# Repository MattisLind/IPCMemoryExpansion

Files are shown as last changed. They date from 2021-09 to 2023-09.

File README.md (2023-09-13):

# HP Integral PC Memory Expansion board

HP Integral PC

The HP Integral PC was a portable 68000 UNIX based computer introduced in 1984. The computer included a floppy drive as mass storage and a printer was built in. The screen was a electroluminicent screen. The computer has a HPIB connector to attach to external devices. External disks can be attached through HPIB.

The computer has a two expansion slot where various peripherals can be installed. For example serial boards or memory expansion boards. It was also possible to install ROM boards. The software engineering ROM has 2Mbyte of ROM expansion and when installed appear as 8 disk devices in the Unix system.

The project aims at creating a 7M RAM and 8M ROM memory expansion to the HP Integral computer. RAM is implemented using a single SRAM chip and ROM is implemented using a single NOR FLASH ROM chip. DIP-switches are used to map the ROM into the various ROM areas of the Integral.

## Levelshifting

All signals are level shifted from 5V TTL to 3.3V LVTTL using six 74LVC245 which has 5V tolerant inputs. The two open-collector signals, NBDTACK and NBIMA is handled by 1 74LS38 chip.

## Address decoding

A Xilinx XC2C32A CPLD is used for all address decoding and ROM remapping. The VHDL is provided [here](https://raw.githubusercontent.com/MattisLind/IPCMemoryExpansion/main/XILINX/IntegralMemExp/main.vhd).

## DIPSWITCH

The board is using a piano-type dipswitch for easy access from the side. When the switch is in the up position in corresponds to the off condition or digital 1 signal. When the switch is in the down position this corresponds to a on condition or 0 signal. X means that the position of the switch is irrelevant.

DIPSW0 to DIPSW5 is used for controlling the ROM mapping in the address space.

DIPSW7 is used for enabling and disabling the busdrivers and DIPSW6 is connected to RESET of the processor. Thus the processor portion can be completely disabled when both these switches are pushed down (on). They should be in the UP (off) position so that the processor runs and can access the memory when trying to upload to the flash memory onboard. When used in the Integral PC they should be in the DOWN (on) position to stop the processor and disable processor access to the memory.

## ROM
The mapping of the FLASH ROM memory is controlled by six dipswitches as follows:

| Integral address range | DIPSW0 | DIPSW1 | DIPSW2 | DIPSW3 | DIPSW4 | DIPSW5 | Flash memory range | Used for |
|---|---|---|---|---|---|---|---|---|
| 000000 - 07FFFF | Down(0) | Down(0) | X | X | X | X |  000000-07FFFF | SYS V ROM|
| 000000 - 07FFFF | Down(0) | Up(1) | X | X | X | X |  080000-0FFFFF | DiagA ROM|
| 000000 - 07FFFF | Up(1) | Down(0) | X | X | X | X |  100000-17FFFF | DiagB ROM|
| 000000 - 07FFFF | Up(1) | Up(1) | X | X | X | X |  NONE | Internal ROM used |
| 080000 - 0FFFFF | X | X | Down(0) | X | X | X |  NONE | NONE |
| 080000 - 0FFFFF | X | X | Up(1) | X | X | X |  180000-1FFFFF | BASIC ROM |
| 100000 - 1FFFFF | X | X | X | X | X | Down(0) |  NONE | |
| 100000 - 1FFFFF | X | X | X | X | X | Up(1) |  600000-6FFFFF | AUX ROM 3|
| 200000 - 3FFFFF | X | X | X | Down(0) | Down(0) | X |  200000-3FFFFF | SE ROM |
| 200000 - 3FFFFF | X | X | X | Down(0) | Up(1) | X |  400000-5FFFFF | AUX ROM 1|
| 200000 - 3FFFFF | X | X | X | Up(1) | X | X |  NONE | NONE |
| 300000 - 4FFFFF | X | X | X | X | X | Down(0) |  NONE | NONE |
| 300000 - 4FFFFF | X | X | X | X | X | Up(1) |  700000-7FFFFF | AUX ROM 2 |

There is a STM32F407ZET SoC makes the board look like a USB stick when the USB port is connected to a host computer. 

The ROM is implemented in one single 8 Mbyte SST38VF6401 chip.

## RAM

Normally Integral memory is implemented using memory board sized up to 1 MByte. Each memory board responds to a read port which provide an ID for the board and a writable base address register. The Integral will use these to identfiy each memory board and configure its starting address. However the memory sizing of HP-UX system is completely independent of the memory configuration descibed preiously meaning that these configuaration is not necessary to get the Integral to detect the full memory. This has been verified using the MAME emulation of the Integral.

All this obviously that it would be very much easier to implement a RAM expansion board since it only requires that it would match the RAM address range 800000-EFFFFF.

The RAM is implemented in one single AS6C6416 4M x 16 SRAM memory chip. 

## Testing and design fault finding.

Obviously when testing the board for the first time it didn't work at all. Of course I tested many different ways to get it working. But in the end I think that one main problem was the use of UDS/LDS instead of AS strobe. On the standard 68000 that would probably have worked just fine. But on the HP Integral he AS strobe is not at all the AS strobe from the processor. It has gone through plenty of logic until the AS signal found in the expasion connector is generated. Thus the use of the AS signal is a must. Gating with that signal made the RAM expansio work fine.

Since the 74LVC245 inputs are CMOS there wil be no current flowing towards the expansion board. When I attached a bus extender board to be able to measure on the board the added buslength seemed to cause trouble. Adding bus terminating resistors at the 74LVC245 inputs seemed to fix the issue. To better adapt the 74LVC245 driver to the bus impedance a low ohm resistor was inserted in the bus line path for the data bus.

All these changes resulted in a second spin of the board.

## Spin 2

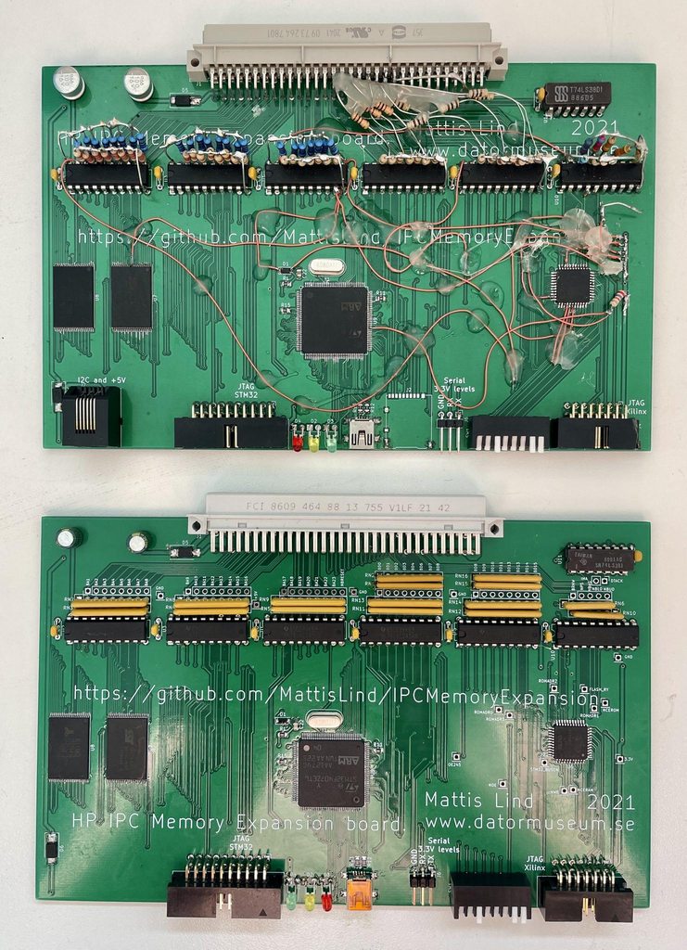
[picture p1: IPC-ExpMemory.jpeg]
Boards


Spin 1 became quite messy when trying to fix all small problems so I decided on a spin 2. I also added test points to make it easier to measure on the board, a major issue on the first spin was that it was so hard to take measurements. After spin 2 came back from the JLCPCB I found that it was virtually impossible to get hold of the STM32 chip and the CPLD, so the project got dormant until sping 2023 when I eventually was able to order chips.

There were some small changes made to the CPLD VHDL code for spin 2 ~~which to this date has not yet been tested (2023-07-24). I hope to be able to test the board soon.~~
Spin 2 has now been tested and appears to work correctly. Follow instructions further down to install the board.

## Firmware

There are two firmwares. One Arduino style .ino-sketch which I used for testing and the a STM32Cube applicaton that is the production code. I used STM32 because it was so simple to wrap up the USB mass storage stuff. The code essentially enables the FSMC controller of the chip and enables the USB mass storage code, then it responds to read and writes to the memory. While the USB-cable is connected the green LED will blink. The yellow LED will blink when a read is performed and the red will blink when a write is performed.

## Installation

There are three steps that need to be taken to install the all needed software/firmware to get the board running.
1. Program the CPLD
2. Install the STM32 firmware
3. Upload integral software to the board

For all these steps the USB connector of the board need to be connected to a USB outlet to the computer. This will thus supply the board with power and in the third step also make the board able to communicate with the host.

### Program the CPLD

The CPLD code is written in VHDL and I have used the Xilinx ISE version 14.7. In order to just install the existing JEDEC file provided in the repo it is only necessary to use the Impact tool in the Xilinx ISE suite. Download, start Impact, attach the Xilinx download cable and make sure that the device is detected. Then select the main.jed file and program the device.

### Install the STM32 firmware

You need both the STM32CubeIDE and STM32CubeProgrammer which has to be downloaded from the ST webpage. Use defaults when installing the software.

When installation is ready start STM32CubeIDE and select the "Open Projects from file System" option in the menu. Select the folder " Software/STM32CubeIDE/workspace_1.7.0 /HP IPC Memory Expansion/" in this repo. In the project menu, select the Build Configurations. This will open a submenu which where you can do "Set Active" Select "Release"

Now do "Build All" from the project menu and the full software will be built.

Now start the STM32CubeProgrammer software nd make sure the STM32 download canle is attached to the board and that power is supplied to the board using the USB cable. In this step DIPSW 6 and DIPSW 7 has to be in the up posistion.

Select the "HP IPC Memory Expansion.elf" binary in the Release folder and do a "Erase and program" operation.

### Uploading Integral software to the board

The idea is to use the Linux dd command to transfer the image-file generated by the build.sh shellscript in ROMS folder. When doing so the red and green LEDs should blink. It should also be possible to read back the content stored using dd and compare with the actual file. It is important to write the image to the topmost 8M of the USB device created when the board is connected over USB. The top 8M is mapped to the flash memory while the lower 8M is mapped to the SRAM.

Thus this command is needed to write the flash:

```
sudo dd if=flash_image.bin of=/dev/sd<x> bs=1k seek=8192
```
where ```/dev/sd<x>``` is the device that is allocated for the mass storage device that the board is acting as. Check using ```dmesg``` what device is created when it is plugged into the USB-port.

## Schematic 

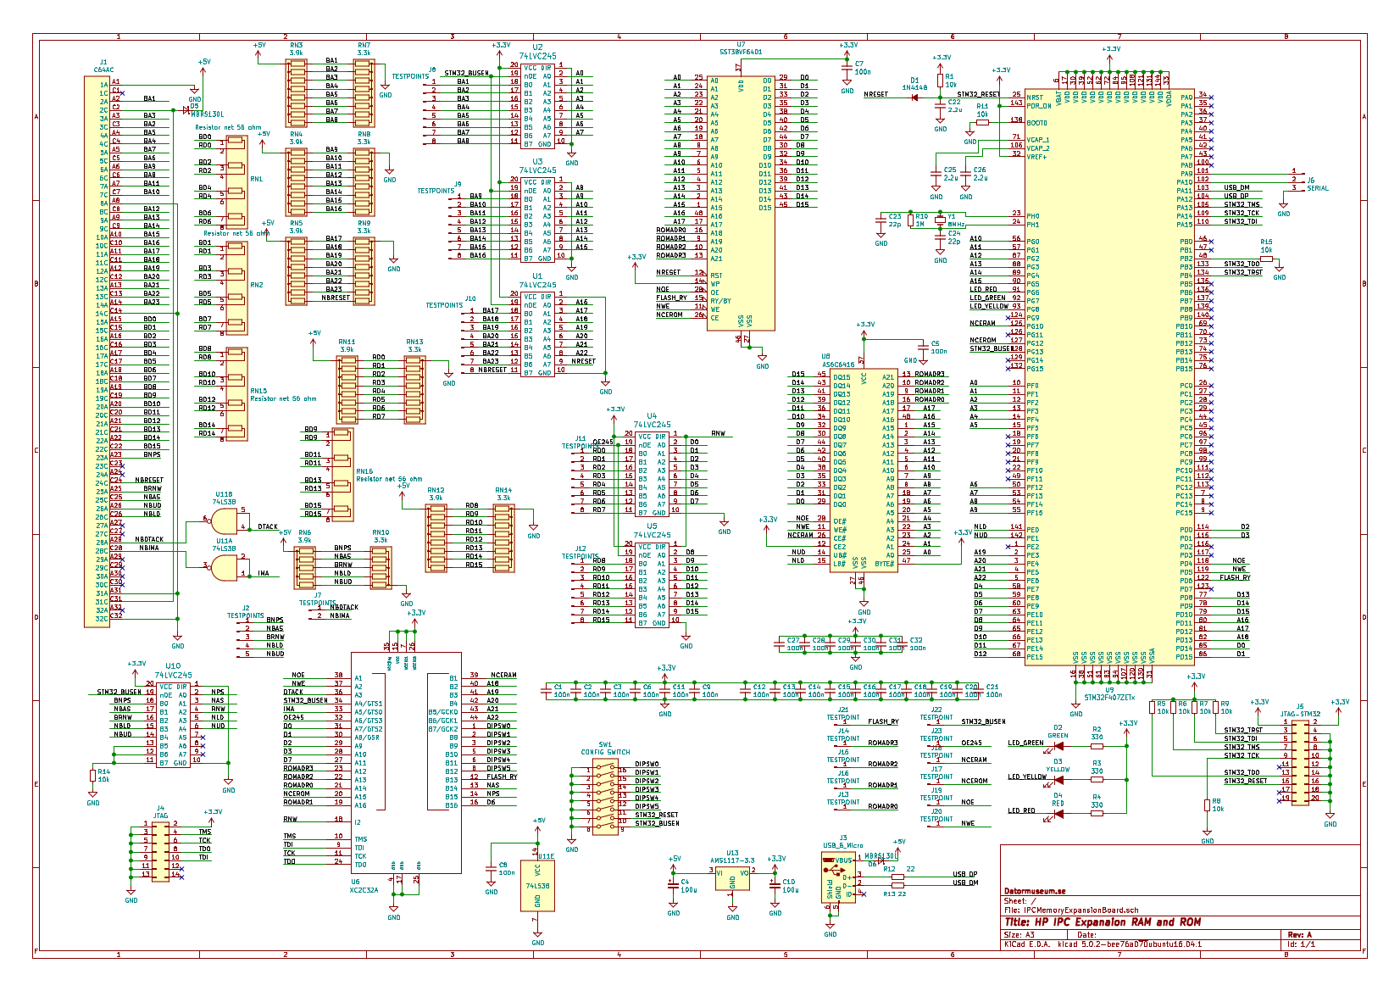
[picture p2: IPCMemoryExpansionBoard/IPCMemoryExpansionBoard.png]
Schematic


## Install instructions by Carl Claunch

After spin 1 was completed I was not able to get components for spin 2 although the board had been fabricated. All this due to the post-covid semiconductor crunch. In July 2023 I got contacted by Carl who had been asked to help out to do the installation of the firmware. As we sorted out how topoerform the steps (which I had more or less forgotten since I initially designed it) he created a nice document which describes the steps do be done. I link it below:

[Install instructions by Carl Claunch](https://github.com/MattisLind/IPCMemoryExpansion/blob/main/HP%20Integral%20board%20instructions.pdf)

## BOM
This is a BOM for the spin 2 board:

| Component designator | Description | Mouser order number | Misc. |
|---|---|---|---|
| R1,R5,R6,R7,R8,R9,R11,R14,R15| 10kOhm SMD 0805 |  -  | |
| R2,R3,R4 | 330 Ohm SMD 0805 | - | |
| R10 | 1MOhm SMD 0805 | - | |
| R12,R13 | 22 Ohm SMD 0805 | - | |
| RN1,RN2,RN15,RN16 |  network 4 x bussed 56 Ohm THT | 652-4608X-2LF-56 | |
| RN3,RN4,RN5,RN6,RN11,RN12 | network 8 x star 3.9 KOhm  THT | 652-4609X-1LF-3.9K | |
| RN10 | network 5 x star 3.3 KOhm THT | 652-4606X-1LF-3.3K | |
| RN7,RN8,RN9,RN10,RN13,RN14 | network 8 x star 3.3 KOhm THT | 652-4609X-1LF-3.3K | |
| RN6 |  network 5 x star 3.9 KOhm | 652-4606X-1LF-3.9K | |
| C1,C2,C3,C5,C6,C7,C8 | 100 nF Ceramic THT, RM5 | - | |
| C4,C10 | 100 uF Electrolytic THT, RM 2.5 | - ||
| C9,C11,C12,C13,C14,C15,C16,C17,C18,<BR>C19,C20,C21,C27,C28,C29,C30,C31,C32 | 100 nF SMD 0805 | - ||
| C22,C25,C26| 2.2 uF SMD, 0805 | - | C25 is on the underside just <BR>below the processor chip,<BR>close to C29. The silkscreen is a bit bad |
| C23,C24 | 22 pF SMD, 0805 | - | |
| D1 | IN4148 SMD | 750-1N4148W-HF | Located on the top side <BR>close to the processor |
| D2 | LED green 3mm THT | 859-LTL-4231N | |
| D3 | LED yellow 3mm THT | 859-LTL-4251N | |
| D4 | LED red 3mm THT | 859-LTL-4221N | |
| D5,D6 | MBRS130L SMD, 2010 | 78-VS-MBRS130L-M35BT | |
| SW1 |  8 DIP switch - piano style THT | 774-1958MS | |
| U1,U2,U3,U4,U5,U10 | 74LVC245 THT | 595-SN74LVC245ANE4 | |
| U6 | XC2C32A SMD | 217-XC2C32A-6VQG44I | |
| U7 | SST38VF6401 SMD | 804-38VF64019CEKE | |
| U8 |  AS6C6416 SMD | 913-AS6C6416-55TIN | |
| U9 | STM32F407ZET  SMD | 511-STM32F407ZET7 | |
| U11 | 74LS38 THT | - | |
| U13 | AMS1117-3.3 SMD | 621-AZ1117CD-3.3TRG1 | Mounted on the bottom side |
| Y1 | Crystal 8 MHz | 815-ABL-8-B2 | |
| J1 | C64AC, 2 x 32 pin, 90 deg angle THT | 617-09732647801 |
| J2,J7,J13,J14,J15,J16,J17,J18,<BR>J19,J20,J21,J22,J23 | Test points | - | Normally not needed |
| J3 | Mini USB | 710-65100516121 | |
| J4 | 2 x 7 pin header, 90 deg angle, RM 2.54 | - | JTAG for Xilinx CPLD |
| J5 | 2 x 10 pin header, 90 deg angle, RM 2.54 | 710-61202021721 | JTAG for STM32 |
| J6 | 3 pin header, 90 deg angle, RM 2.54 | 538-22-28-8031 | Serial output |

## Links

[HP Museum page on the Integral PC](http://www.hpmuseum.net/display_item.php?hw=122)
<BR>[Peter Johnsons page on the Integral PC](http://www.coho.org/~pete/IPC/integral.html)

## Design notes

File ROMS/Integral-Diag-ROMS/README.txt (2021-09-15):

HP Integral PC Diagnostic ROM Files README	Mark Bielman January 2018
=========================================================================

This archive contains 2 sets of EPROM files extracted from EPROMS that were
found in my parts stash. (from my work at HP-Corvallis on the Integral)
The sets are quite different! (but the PC boards are identical)

Designated as "Board A" and "Board B", each directory contains HEX and BIN
versions of each of the 4 EPROMS. (U1 through U4) Since the 68000 has a
16-bit data bus, the ROMs are accessed in pairs: U1/U2 and U3/U4.

I also included 'merged' files of the ROM pairs in order to view the ASCII
text messages that might appear. (errors, etc)

Board A
=======
When installed, the PC opens a small screen stating the amount internal RAM
and plug-in RAM. It then asks that a "boot disc" be installed. (no idea!)
Not a full diagnostic but should verify the PC core is working. From the text,
it appears that 0.5 MB of internal RAM is always reported. (?)

U1 = U2 = U3 = U4 = 2764

Board B
=======
From the messages/errors listed, this looks like the ROMs I used in manufacturing.
These are NOT the ROMs described in the Service Manual! (best I can tell) When
installed, the display will say it's running a quick system test (RAM, keyboard,
GPU, etc) then bring up softkeys to run specific tests. Best I can tell, they work.

U1= U2 = 27128
U3 = U4 = 2764

Notes on the PCB
================
I have NOT beeped out the boards so not sure how they handle DTACK here.

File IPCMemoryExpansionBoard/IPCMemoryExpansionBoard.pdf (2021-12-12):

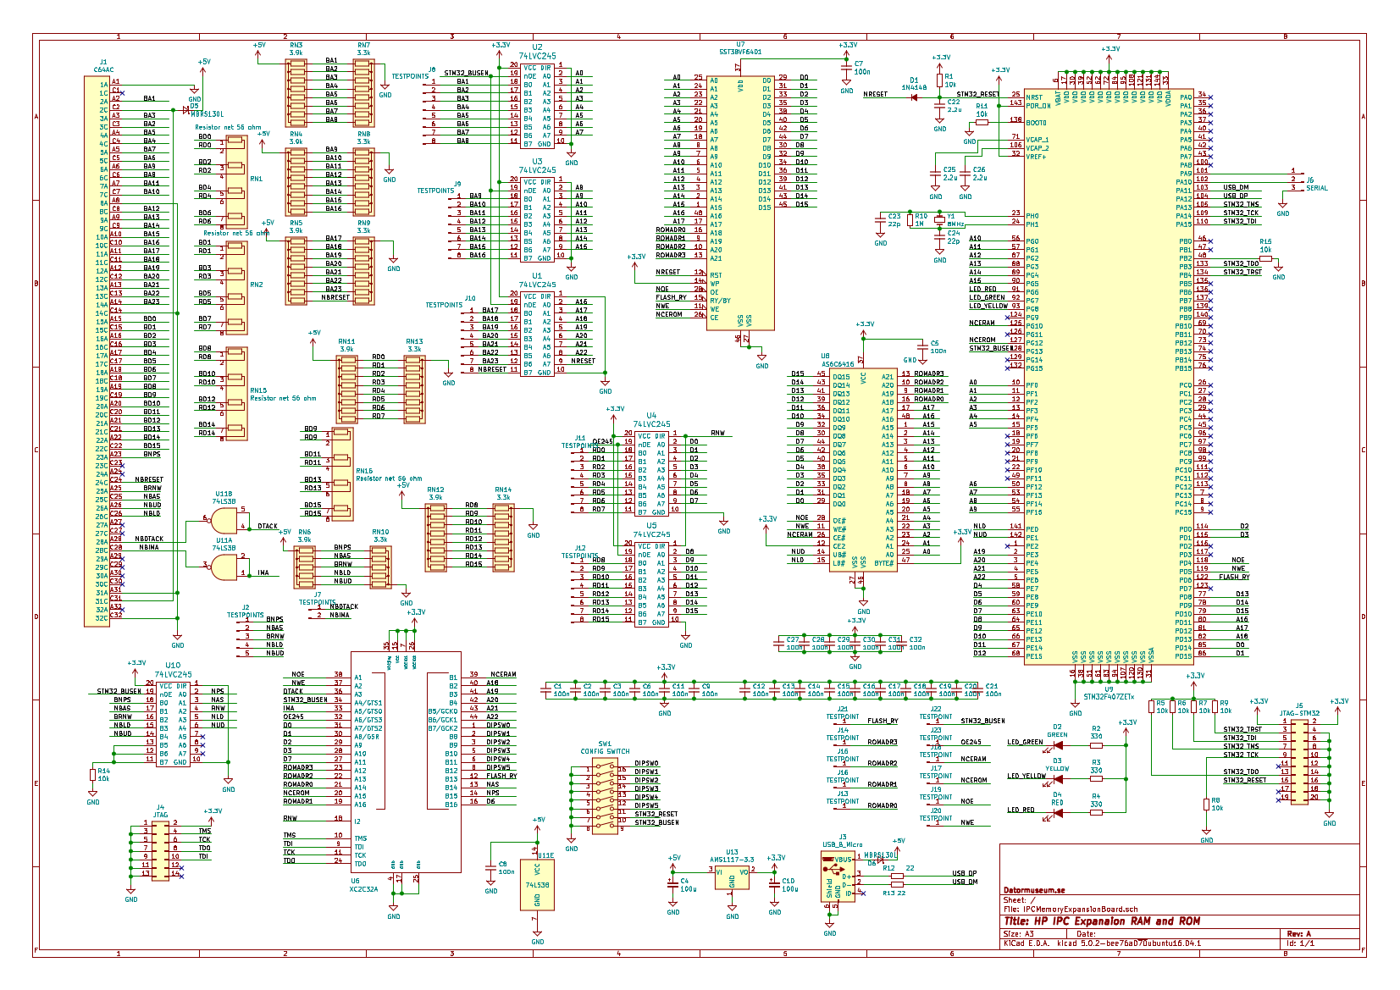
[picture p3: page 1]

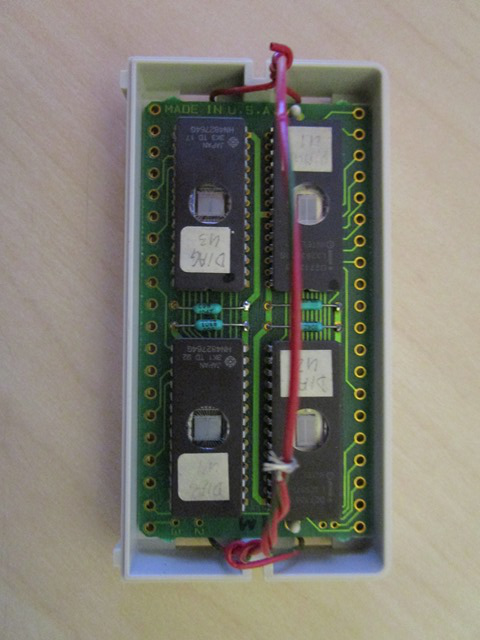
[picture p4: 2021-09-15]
ROMS/Integral-Diag-ROMS/Assy.jpg

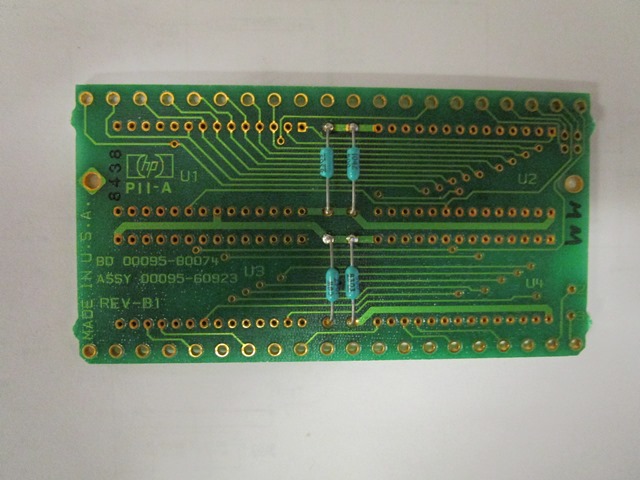
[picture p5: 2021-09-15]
ROMS/Integral-Diag-ROMS/PCB-Top.jpg

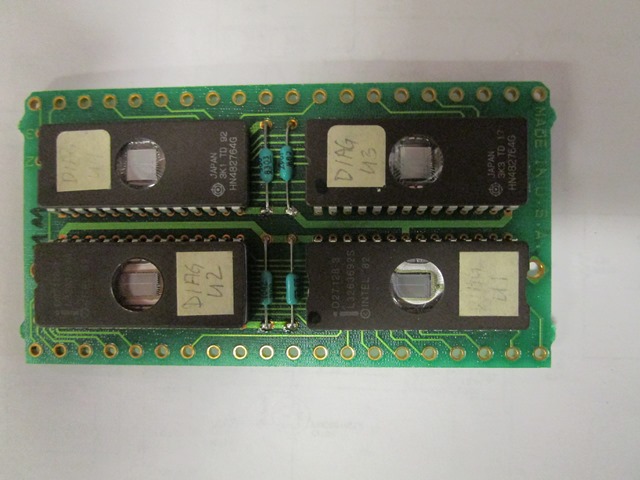
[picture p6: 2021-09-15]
ROMS/Integral-Diag-ROMS/PCA-Top.jpg

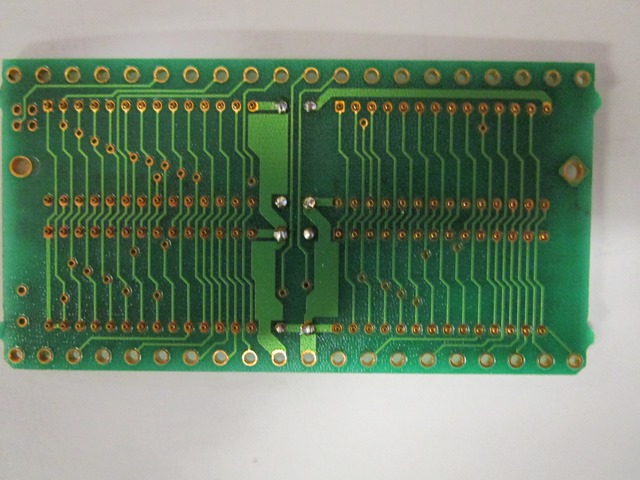
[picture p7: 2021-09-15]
ROMS/Integral-Diag-ROMS/PCB-Bottom.jpg

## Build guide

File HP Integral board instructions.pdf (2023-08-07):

Version 3

Operating with the board in the HP Integral PC

The board is designed to have the microcontroller disabled in normal operation. Turn both dipswitches 6 and 7 to the on position. This disables the STM32 microprocessor and disables its access to the memory devices on the board.

On this board, when the LEDs are pointing down and the dipswtich is along the bottom, on means the dipswitch is up and off means the dipswitch is down.

Dipswitches 0 to 5 are set to choose which of the ROM images will appear to be inserted into expansion slots and thus available. It is not a one to one association of switches to ROM images.

This board runs only the internal ROM on the PC, if plugged in, when dipswitches 0 and 1 are both on. To run on the newer Unix System V image, remove the internal ROM and turn both of these switches off.

The Basic ROM is enabled by turning dipswitch 2 on.

Enabling the development (SE) ROM is done by setting both dipswitch 3 and dipswitch 4 off.

Thus the most common settings would be 001000 in dipswitches 0 to 5, on - on - off - on - on - on giving System V with Basic and SE. This is Up Up Down Up Up Up Up UP

One has the ability to instead run on diagnostic ROM images instead of Unix. These are files pulled off of boards kept by a former HP employee at the factory. He labeled the boards A and B which correspond to the two ROM images. The internal ROM must be removed to run either of these images.

Board A will perform a quick CPU test but then stalls waiting for some kind of external boot disk that is not available. Board B performs a more extensive self check and then offers menus of diagnostic tests that one could run.

The Diagnostic rom A can be activated by setting dipswitch 0 off and dipswitch 1 on. The Diagnostic rom B will be activated by setting dipswitch 0 on and dipswitch 1 off.

The board provides the ability to activate up to three additional ROM images, labeled Aux 1, Aux 2 and Aux 3. These allow the user to customize their own ROM or to make their applications nonvolatile.

Aux 1 is selected by setting dipswitch 3 off and dipswitch 4 on. It replaces the SE ROM as it uses the same address range.

Aux 2 and Aux3 are both selected by setting dipswitch 5 on and these are in addition to other ROMs you have activated.

Any pattern not listed above may disable other ROMs and not work properly.

Updating the CPLD (FPGA) chip on the board

If you have to update the Xilinx chip because Mattis Lind provides updated source code for the field programmable device, you will have to remove the board from the HP Integral PC and put it on a workbench.

First you will need to install the Xilinx ISE toolchain if you don’t already have it running in your workshop. For newer versions of Windows (10 and above) they provide Oracle VM Virtualbox (VMBox) and the toolchain in a virtual machine running inside VMBox.

This works MUCH better than prior Windows versions of ISE which choked on a kludgy implementation of Linux under Windows to host their software so I highly recommend this version. Download it from https://www.xilinx.com/member/forms/download/xef.html?filename=Xilinx_ISE_14.7_Win10_14.7_VM_0213_1.zip (https://www.xilinx.com/member/forms/download/xef.html?filename=Xilinx_ISE_14.7_Win10_14.7_VM_0213_1.zip) You may have to register with AMD in order to download the software.

The updated code for the field programmable chip will come in a folder that includes the project file as well as the VHDL source. This is what you open in order to compile the new version and to download it onto the board.

Start VMBox and then double click on the Xilinx virtual machine to start that it. It will start up with a graphical desktop interface having a few icons. Double click on the Project Navigator icon to open the toolchain.

Open the project by selecting Open Project from the File manu and then navigating to the location where you have the new project files installed. Inside that folder it will show the filename IntegralMemExp.xise for the project. Select that and let it open.

Under the menu Process you will select Implement Top Module which compiles the code and readies it to load into the field programmable chip on your board.

Install the programmer box by plugging in the USB cable. The ribbon cable from the programmer box is hooked to the 10 pin double row connector on the left of the board labeled JTAG-Xilinx.

Make sure that the connector is oriented with the red wire on the cable at the right as shown in this image:

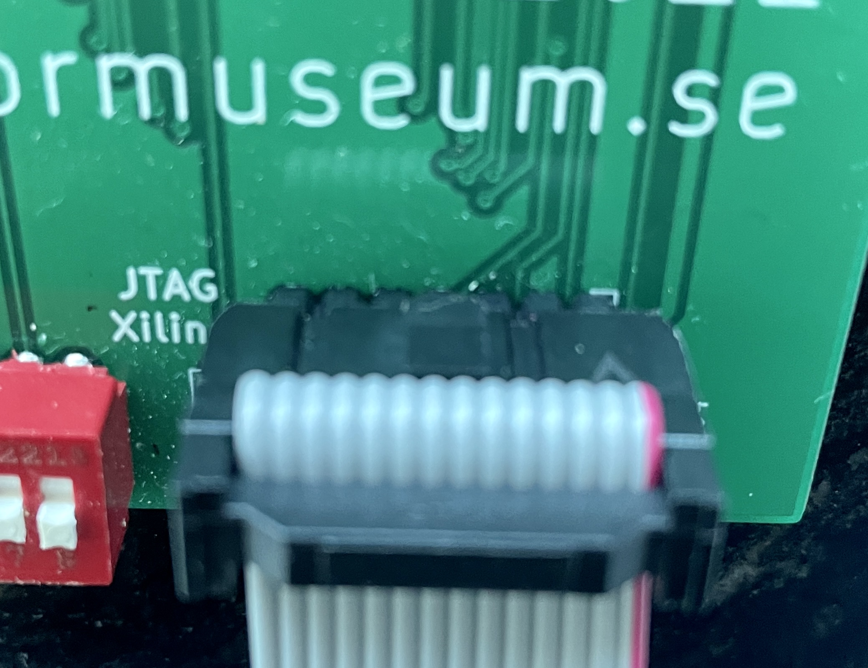
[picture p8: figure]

You will have to supply power to the board with a bench power supply to complete the loading of the new code. Hook the power supply with the positive lead to the small pin labeled 3.3V and the ground lead to the small pin on the board labeled ground. When you turn on the supply (properly adjusted to 3.3V DC) you will see a draw somewhere between 100 and 200ma.

Select the Impact entry from the Tools menu of Project Navigator. This brings up the programming functionality in the toolchain.

Select Launch Wizard from the Edit menu. The action to take is the top one, Configure Devices which will find your programmer device and then scan for the chip.

The tool will ask you if you want to add a configuration file. Choose Yes and navigate to the xxxx.jed file for the project.

You should see a graphical image of the chip show up in the window of the tool. Right click on the icon and select Program to program the device. You should see a positive acknowledgement message. You can also perform the Verify function by right clicking the icon, running it to test the contents of the chip against the updated file you generated on the PC.

Turn off the bench power supply, shut down the Project Navigator and other software, turn off the Xilinx Virtual machine by ACPI Shutdown and quit VMBox. Unplug the programmer box from the PC. Disconnect the ribbon cable from the board. You are done.

Updating the STM32 (microcontroller) chip on the board

If you have to update the microcontroll (STM32) chip because Mattis Lind provides updated source code for the processor, you will have to remove the board from the HP Integral PC and put it on a workbench.

You will need to download and install the STM32Cube IDE software if it is not already available in your workbench environment. Get it from https://www.st.com/en/developmenttools/stm32cubeide.html (https://www.st.com/en/development-tools/stm32cubeide.html)

You also must install the STM32Cube Programmer which loads the software onto the chip. Get it at https://www.st.com/en/development-tools/stm32cubeprog.html (https://www.st.com/en/development-tools/stm32cubeprog.html)

After installation, start the IDE and then select Open Projects from File System from the File menu to open the project from its folder.

In Project manu, select Build Configurations. That opens a subment where you select Set Active and that gives you two choices. Select Release.

Select Build All from the Project menu to compile the source code. Once it has completed successfully, it is time to install it on the microcontroller on the board. The binary file to load is in the Release folder inside the project folder which you opened to work on this software.

You will have to supply power to the board with a bench power supply to complete the loading of the new code. Hook the power supply with the positive lead to the small pin labeled 3.3V and the ground lead to the small pin on the board labeled ground. When you turn on the supply (properly adjusted to 3.3V DC) you will see a draw somewhere between 100 and 200ma.

Connect the ST-Link V2 programming unit to the double row 20 pin connector on the right side of the board. Make sure the connector has the red wire on the right.

In the STM32 Cube Programmer software, click on the three lines at the top left to open the left menu. Select the second item, Erasing and Programming. Browse to the file path from the left top section to pick the file HP IPC Memory Expansion.elf

Dipswitch 6 and dipswitch 7 should be up in order to do this.

On the right side you should see that it has found the ST-Link device hooked to the board via a USB cable to this PC. Check the box to do a verificatio of the image after it is loaded. Push the button marked Program to download the new code to the chip. You should see a message indicating successful completion.

Turn off the bench power supply, remove the ribbon cable, close the IDE on the PC and you are done. Set dipswitches 6 and 7 down to ready the board for normal use inside the HP Integral PC.

Loading ROM images to the board

If you choose to update the ROM images stored in flash chips on the board, you will have to remove the board from the HP Integral PC and put it on a workbench. You might do this to add your own code as AUX 1, 2 or 3.

Set dipswitch 6 off and dipswitch 7 off. This turns on the microcontroller and enables its control over the memory chips on the board.

The USB cable will supply power to the board where the 5V is converted down to 3.3V for the rest of the circuit.

Plug a USB cable into the board and into your PC. You should see a message that a new USB storage disk is connected and that it does not have a valid file system on it. Cancel the offer to format the drive.

Instead, you should start the Oracle VMBox and open a terminal window. Type lsblk and write down what entries start with sd -these can be sda, sda1, sdb and others.

In VMBox and choose the USB menu to select the STM32 USB device that is in the menu list. This attaches it to Unix instead of Windows. On the desktop, right click and select Open Terminal.

Type lsblk and you should see an addition device starting with sd. On my linux image it was /dev/sdb but it is important to use only the new device name which is the board masquerading as a USB storage/thumb drive, whether that is sdb or another. .

This project provides a ROM folder. Inside it are the images of the various ROMs that are to be programmed into the board. Put updates here if you have a changed ROM to install. Copy this folder (ROM) into the shared file folder that is set up to let both Unix in the VMBox and Windows share files.

In the terminal window, navigate via cd commands to get into the ROM folder that VMBox shares from Windows.

There is a Linux script build.sh that copies the different ROM images into a single image file called flash-image.bin that will be used to load your board. Modify if necessary for your code.

Run that script by typing ./build.sh in the window. The file is now ready to load. Enter the command
sudo dd if=flash-image.bin of=/dev/sdX bs=1k seek=8192 where you use the name you found instead of sdX. That will copy the file over the USB cable. You will see the LEDs on the board flash in patterns as it receives the file and flashes the chips with that data.

This will program the flash memory on the board with all the ROM images so that you can select and use them via the dipswitches when the board is intalled in the HP Integral PC.

Unplug the USB cable. Shut down VMBox if you used that for a Linux/Unix shell. Turn dip switches 6 and 7 on. Set dipswitches 0 to 5 with the patterns to activate the ROM images you wish to use, usually 001000 (on on off on on on).

Reinsert the board into the HP Integral PC and make use of your

new/updated ROM images.

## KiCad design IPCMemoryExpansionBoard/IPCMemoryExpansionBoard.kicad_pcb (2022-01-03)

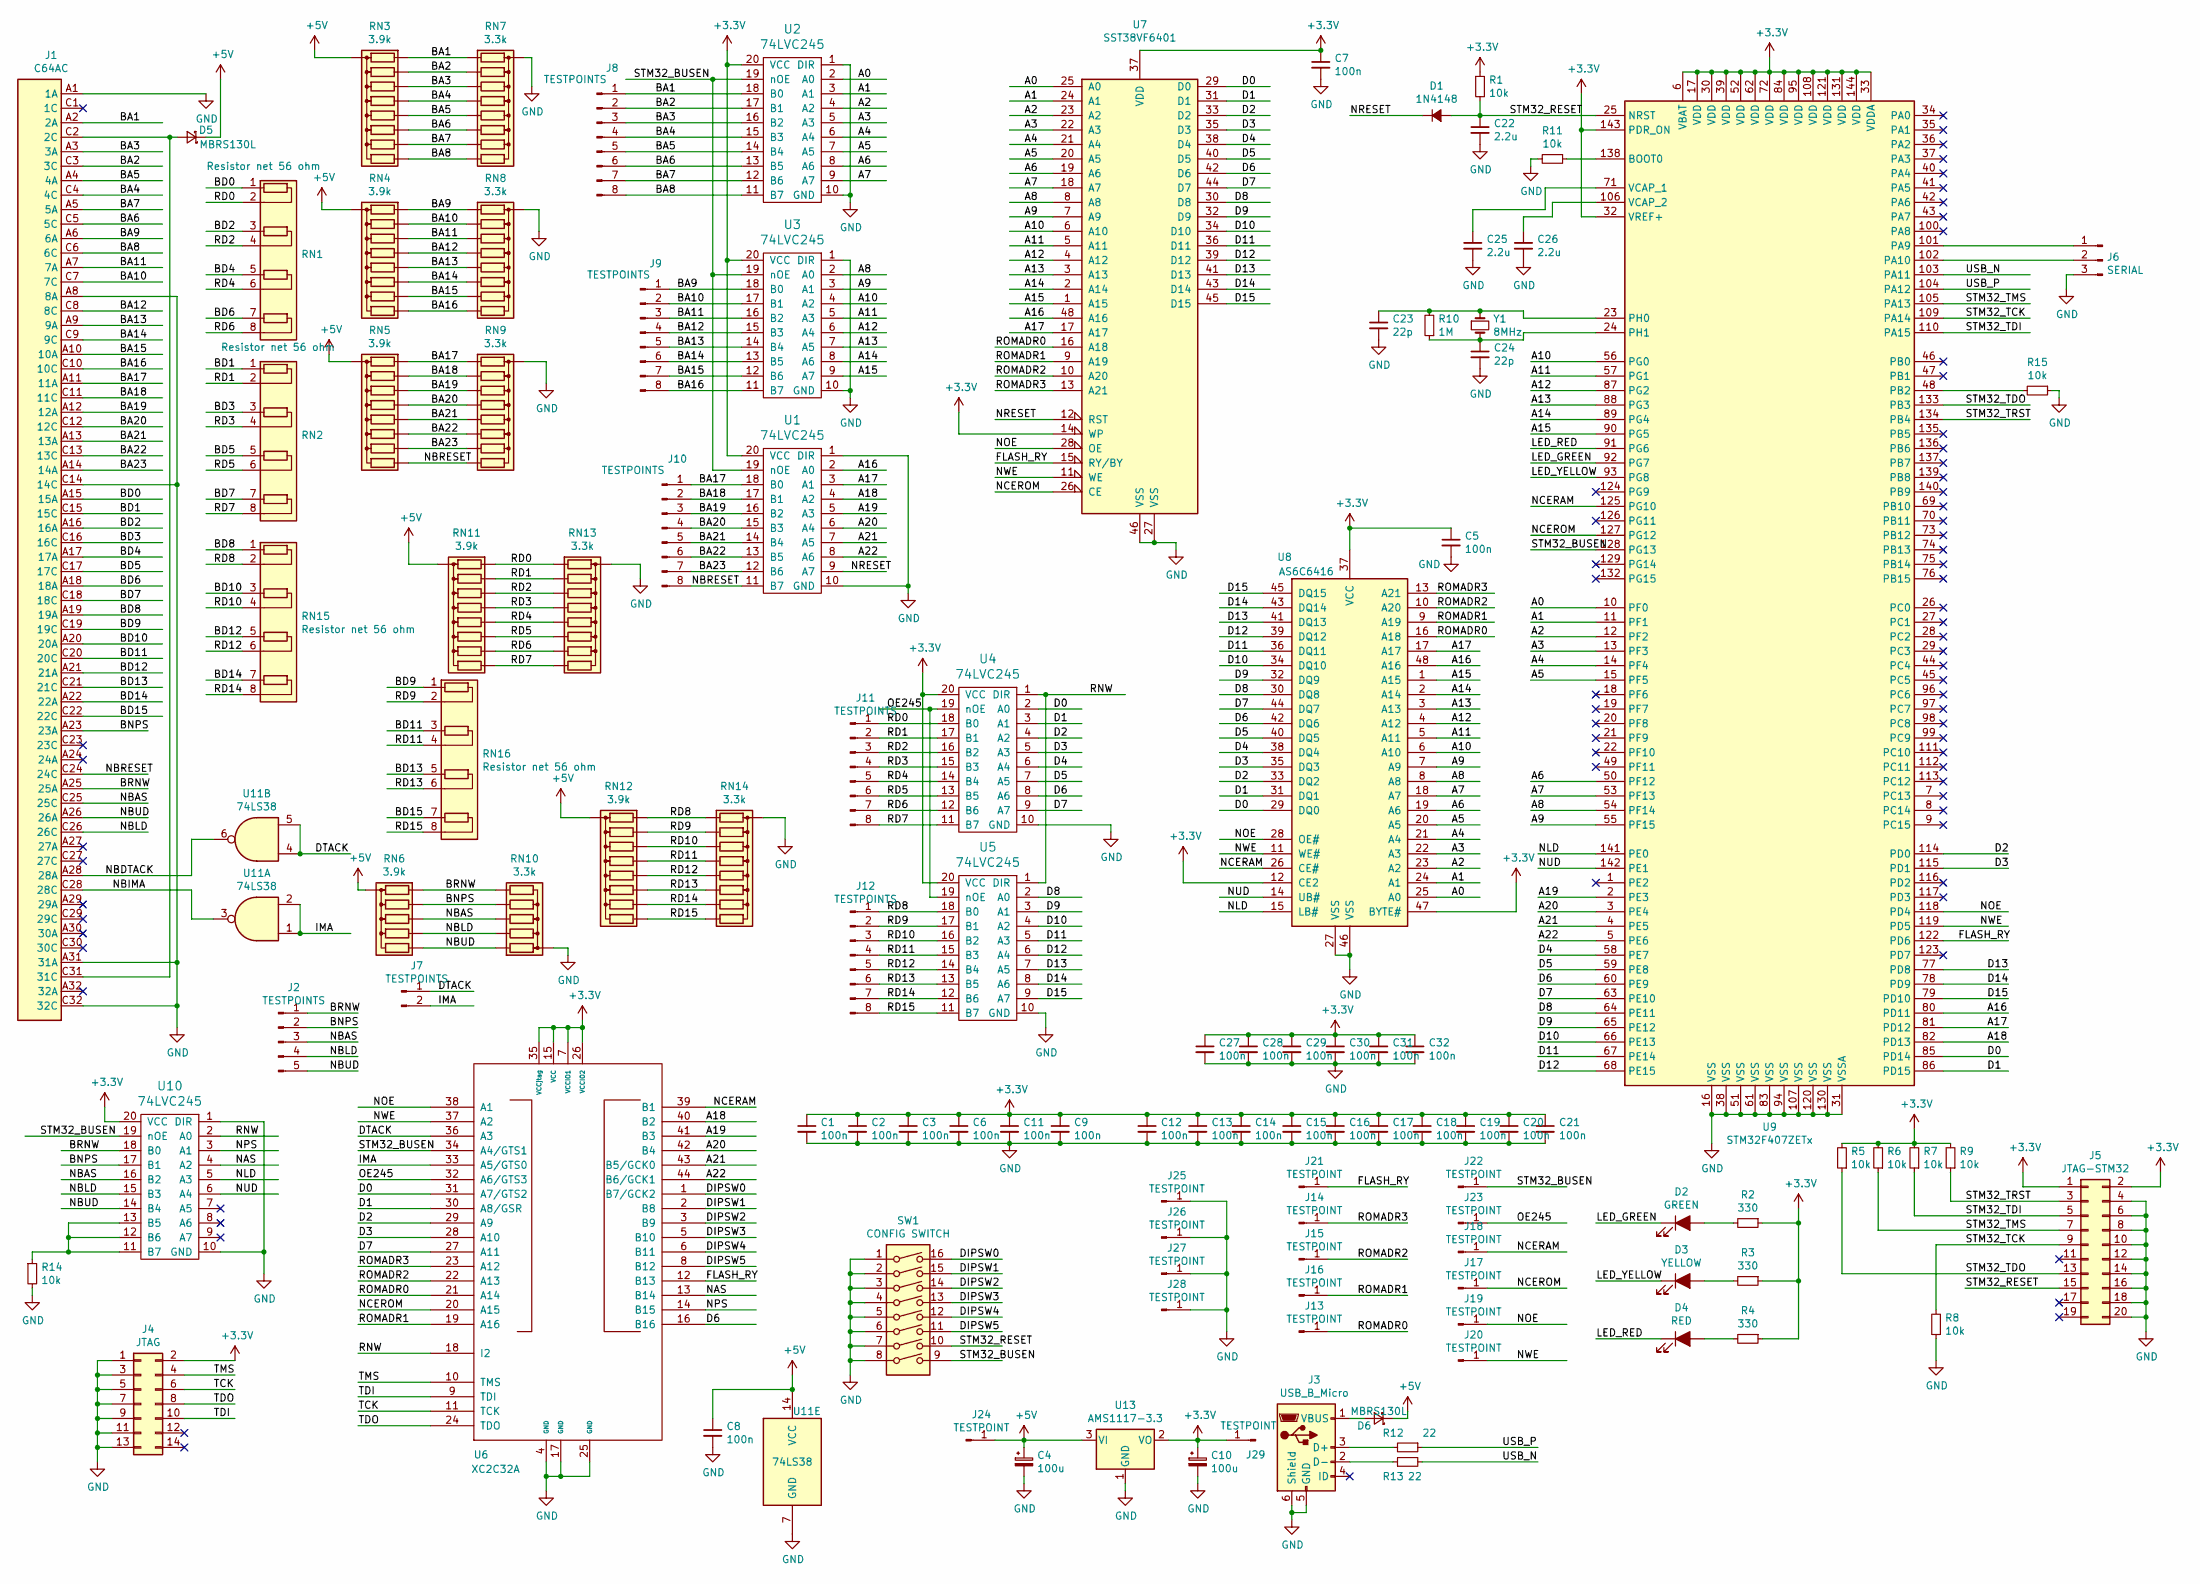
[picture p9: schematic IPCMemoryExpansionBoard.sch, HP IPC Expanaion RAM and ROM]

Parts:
C1, C2, C3, C5, C6, C7, C8: 100n; C_Disc_D4.3mm_W1.9mm_P5.00mm
C4, C10: 100u; CP_Radial_D5.0mm_P2.50mm
C9, C11, C12, C13, C14, C15, C16, C17, C18, C19, C20, C21, C27, C28, C29, C30, C31, C32: 100n; C_0805_2012Metric_Pad1.15x1.40mm_HandSolder
C22, C25, C26: 2.2u; C_0805_2012Metric_Pad1.15x1.40mm_HandSolder
C23, C24: 22p; C_0805_2012Metric_Pad1.15x1.40mm_HandSolder
D1: 1N4148; D_SOD-123
D2: GREEN; LED_D3.0mm_Horizontal_O1.27mm_Z2.0mm
D3: YELLOW; LED_D3.0mm_Horizontal_O1.27mm_Z2.0mm
D4: RED; LED_D3.0mm_Horizontal_O1.27mm_Z2.0mm
D5, D6: MBRS130L; D_SMB_Handsoldering
J1: C64AC; DIN41612_C_2x32_Male_Horizontal_THT
J2: TESTPOINTS; PinHeader_1x05_P2.54mm_Vertical
J3: USB_B_Micro; USB_Mini-B_Lumberg_2486_01_Horizontal
J4: JTAG; IDC-Header_2x07_P2.54mm_Horizontal
J5: JTAG-STM32; IDC-Header_2x10_P2.54mm_Horizontal
J6: SERIAL; PinHeader_1x03_P2.54mm_Horizontal
J7: TESTPOINTS; PinHeader_1x02_P2.54mm_Vertical
J8, J9, J10, J11, J12: TESTPOINTS; PinHeader_1x08_P2.54mm_Vertical
J13, J14, J15, J16, J17, J18, J19, J20, J21, J22, J23, J24, J25, J26, J27, J28, J29: TESTPOINT; PinHeader_1x01_P2.54mm_Vertical
R1, R5, R6, R7, R8, R9, R11, R14, R15: 10k; R_0805_2012Metric_Pad1.15x1.40mm_HandSolder
R2, R3, R4: 330; R_0805_2012Metric_Pad1.15x1.40mm_HandSolder
R10: 1M; R_0805_2012Metric_Pad1.15x1.40mm_HandSolder
R12, R13: 22; R_0805_2012Metric_Pad1.15x1.40mm_HandSolder
RN1, RN2, RN15, RN16: Resistor net 56 ohm; R_Array_SIP8
RN3, RN4, RN5, RN11, RN12: 3.9k; R_Array_SIP9
RN6: 3.9k; R_Array_SIP6
RN7, RN8, RN9, RN13, RN14: 3.3k; R_Array_SIP9
RN10: 3.3k; R_Array_SIP6
SW1: CONFIG SWITCH; DIP-16_W7.62mm
U1, U2, U3, U4, U5, U10: 74LVC245; DIP-20_W7.62mm
U6: XC2C32A; TQFP-44_10x10mm_P0.8mm
U7: SST38VF6401; TSOP-I-48_18.4x12mm_P0.5mm
U8: AS6C6416; TSOP-I-48_18.4x12mm_P0.5mm
U9: STM32F407ZETx; LQFP-144_20x20mm_P0.5mm
U11: 74LS38; DIP-14_W7.62mm
U13: AMS1117-3.3; SOT-223-3_TabPin2
Y1: 8MHz; Crystal_HC49-U_Vertical

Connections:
+3V3: C1.1, C2.1, C3.1, C5.1, C6.1, C7.1, C9.1, C10.1, C11.1, C12.1, C13.1, C14.1, C15.1, C16.1, C17.1, C18.1, C19.1, C20.1, C21.1, C27.1, C28.1, C29.1, C30.1, C31.1, C32.1, J4.2, J5.1, J5.2, J29.1, R1.1, R2.1, R3.1, R4.1, R5.2, R6.2, R7.2, R9.2, U1.20 (VCC), U2.20 (VCC), U3.20 (VCC), U4.20 (VCC), U5.20 (VCC), U6.7 (VCCIO1), U6.15 (VCC), U6.26 (VCCIO2), U6.35 (VCCjtag), U7.14 (WP), U7.37 (VDD), U8.12 (CE2), U8.37 (VCC), U8.47 (BYTE#), U9.6 (VBAT), U9.17 (VDD), U9.30 (VDD), U9.32 (VREF+), U9.33 (VDDA), U9.39 (VDD), U9.52 (VDD), U9.62 (VDD), U9.72 (VDD), U9.84 (VDD), U9.95 (VDD), U9.108 (VDD), U9.121 (VDD), U9.131 (VDD), U9.143 (PDR_ON), U9.144 (VDD), U10.20 (VCC), U13.2 (VO)
+5V: C4.1, C8.1, D5.1 (K), D6.1 (K), J24.1, RN3.1 (common), RN4.1 (common), RN5.1 (common), RN6.1 (common), RN11.1 (common), RN12.1 (common), U11.14 (VCC), U13.3 (VI)
/A0: U2.2 (A0), U7.25 (A0), U8.25 (A0), U9.10 (PF0)
/A1: U2.3 (A1), U7.24 (A1), U8.24 (A1), U9.11 (PF1)
/A2: U2.4 (A2), U7.23 (A2), U8.23 (A2), U9.12 (PF2)
/A3: U2.5 (A3), U7.22 (A3), U8.22 (A3), U9.13 (PF3)
/A4: U2.6 (A4), U7.21 (A4), U8.21 (A4), U9.14 (PF4)
/A5: U2.7 (A5), U7.20 (A5), U8.20 (A5), U9.15 (PF5)
/A6: U2.8 (A6), U7.19 (A6), U8.19 (A6), U9.50 (PF12)
/A7: U2.9 (A7), U7.18 (A7), U8.18 (A7), U9.53 (PF13)
/A8: U3.2 (A0), U7.8 (A8), U8.8 (A8), U9.54 (PF14)
/A9: U3.3 (A1), U7.7 (A9), U8.7 (A9), U9.55 (PF15)
/A10: U3.4 (A2), U7.6 (A10), U8.6 (A10), U9.56 (PG0)
/A11: U3.5 (A3), U7.5 (A11), U8.5 (A11), U9.57 (PG1)
/A12: U3.6 (A4), U7.4 (A12), U8.4 (A12), U9.87 (PG2)
/A13: U3.7 (A5), U7.3 (A13), U8.3 (A13), U9.88 (PG3)
/A14: U3.8 (A6), U7.2 (A14), U8.2 (A14), U9.89 (PG4)
/A15: U3.9 (A7), U7.1 (A15), U8.1 (A15), U9.90 (PG5)
/A16: U1.2 (A0), U7.48 (A16), U8.48 (A16), U9.80 (PD11)
/A17: U1.3 (A1), U7.17 (A17), U8.17 (A17), U9.81 (PD12)
/A18: U1.4 (A2), U6.40 (B2), U9.82 (PD13)
/A19: U1.5 (A3), U6.41 (B3), U9.2 (PE3)
/A20: U1.6 (A4), U6.42 (B4), U9.3 (PE4)
/A21: U1.7 (A5), U6.43 (B5/GCK0), U9.4 (PE5)
/A22: U1.8 (A6), U6.44 (B6/GCK1), U9.5 (PE6)
/BA1: J1.A2 (2A), J8.1, RN3.2 (R1), RN7.2 (R1), U2.18 (B0)
/BA2: J1.C3 (3C), J8.2, RN3.3 (R2), RN7.3 (R2), U2.17 (B1)
/BA3: J1.A3 (3A), J8.3, RN3.4 (R3), RN7.4 (R3), U2.16 (B2)
/BA4: J1.C4 (4C), J8.4, RN3.5 (R4), RN7.5 (R4), U2.15 (B3)
/BA5: J1.A4 (4A), J8.5, RN3.6 (R5), RN7.6 (R5), U2.14 (B4)
/BA6: J1.C5 (5C), J8.6, RN3.7 (R6), RN7.7 (R6), U2.13 (B5)
/BA7: J1.A5 (5A), J8.7, RN3.8 (R7), RN7.8 (R7), U2.12 (B6)
/BA8: J1.C6 (6C), J8.8, RN3.9 (R8), RN7.9 (R8), U2.11 (B7)
/BA9: J1.A6 (6A), J9.1, RN4.2 (R1), RN8.2 (R1), U3.18 (B0)
/BA10: J1.C7 (7C), J9.2, RN4.3 (R2), RN8.3 (R2), U3.17 (B1)
/BA11: J1.A7 (7A), J9.3, RN4.4 (R3), RN8.4 (R3), U3.16 (B2)
/BA12: J1.C8 (8C), J9.4, RN4.5 (R4), RN8.5 (R4), U3.15 (B3)
/BA13: J1.A9 (9A), J9.5, RN4.6 (R5), RN8.6 (R5), U3.14 (B4)
/BA14: J1.C9 (9C), J9.6, RN4.7 (R6), RN8.7 (R6), U3.13 (B5)
/BA15: J1.A10 (10A), J9.7, RN4.8 (R7), RN8.8 (R7), U3.12 (B6)
/BA16: J1.C10 (10C), J9.8, RN4.9 (R8), RN8.9 (R8), U3.11 (B7)
/BA17: J1.A11 (11A), J10.1, RN5.2 (R1), RN9.2 (R1), U1.18 (B0)
/BA18: J1.C11 (11C), J10.2, RN5.3 (R2), RN9.3 (R2), U1.17 (B1)
/BA19: J1.A12 (12A), J10.3, RN5.4 (R3), RN9.4 (R3), U1.16 (B2)
/BA20: J1.C12 (12C), J10.4, RN5.5 (R4), RN9.5 (R4), U1.15 (B3)
/BA21: J1.A13 (13A), J10.5, RN5.6 (R5), RN9.6 (R5), U1.14 (B4)
/BA22: J1.C13 (13C), J10.6, RN5.7 (R6), RN9.7 (R6), U1.13 (B5)
/BA23: J1.A14 (14A), J10.7, RN5.8 (R7), RN9.8 (R7), U1.12 (B6)
/BD0: J1.A15 (15A), RN1.1 (R1.1)
/BD1: J1.C15 (15C), RN2.1 (R1.1)
/BD2: J1.A16 (16A), RN1.3 (R2.1)
/BD3: J1.C16 (16C), RN2.3 (R2.1)
/BD4: J1.A17 (17A), RN1.5 (R3.1)
/BD5: J1.C17 (17C), RN2.5 (R3.1)
/BD6: J1.A18 (18A), RN1.7 (R4.1)
/BD7: J1.C18 (18C), RN2.7 (R4.1)
/BD8: J1.A19 (19A), RN15.1 (R1.1)
/BD9: J1.C19 (19C), RN16.1 (R1.1)
/BD10: J1.A20 (20A), RN15.3 (R2.1)
/BD11: J1.C20 (20C), RN16.3 (R2.1)
/BD12: J1.A21 (21A), RN15.5 (R3.1)
/BD13: J1.C21 (21C), RN16.5 (R3.1)
/BD14: J1.A22 (22A), RN15.7 (R4.1)
/BD15: J1.C22 (22C), RN16.7 (R4.1)
/BNPS: J1.A23 (23A), J2.2, RN6.3 (R2), RN10.5 (R4), U10.17 (B1)
/BRNW: J1.A25 (25A), J2.1, RN6.2 (R1), RN10.6 (R5), U10.18 (B0)
/D0: U4.2 (A0), U6.31 (A7/GTS2), U7.29 (D0), U8.29 (DQ0), U9.85 (PD14)
/D1: U4.3 (A1), U6.30 (A8/GSR), U7.31 (D1), U8.31 (DQ1), U9.86 (PD15)
/D2: U4.4 (A2), U6.29 (A9), U7.33 (D2), U8.33 (DQ2), U9.114 (PD0)
/D3: U4.5 (A3), U6.28 (A10), U7.35 (D3), U8.35 (DQ3), U9.115 (PD1)
/D4: U4.6 (A4), U7.38 (D4), U8.38 (DQ4), U9.58 (PE7)
/D5: U4.7 (A5), U7.40 (D5), U8.40 (DQ5), U9.59 (PE8)
/D6: U4.8 (A6), U6.16 (B16), U7.42 (D6), U8.42 (DQ6), U9.60 (PE9)
/D7: U4.9 (A7), U6.27 (A11), U7.44 (D7), U8.44 (DQ7), U9.63 (PE10)
/D8: U5.2 (A0), U7.30 (D8), U8.30 (DQ8), U9.64 (PE11)
/D9: U5.3 (A1), U7.32 (D9), U8.32 (DQ9), U9.65 (PE12)
/D10: U5.4 (A2), U7.34 (D10), U8.34 (DQ10), U9.66 (PE13)
/D11: U5.5 (A3), U7.36 (D11), U8.36 (DQ11), U9.67 (PE14)
/D12: U5.6 (A4), U7.39 (D12), U8.39 (DQ12), U9.68 (PE15)
/D13: U5.7 (A5), U7.41 (D13), U8.41 (DQ13), U9.77 (PD8)
/D14: U5.8 (A6), U7.43 (D14), U8.43 (DQ14), U9.78 (PD9)
/D15: U5.9 (A7), U7.45 (D15), U8.45 (DQ15), U9.79 (PD10)
/DIPSW0: SW1.16, U6.1 (B7/GCK2)
/DIPSW1: SW1.15, U6.2 (B8)
/DIPSW2: SW1.14, U6.3 (B9)
/DIPSW3: SW1.13, U6.5 (B10)
/DIPSW4: SW1.12, U6.6 (B11)
/DIPSW5: SW1.11, U6.8 (B12)
/DTACK: J7.1, U6.36 (A3), U11.4, U11.5
/FLASH_RY: J21.1, U6.12 (B13), U7.15 (RY/BY), U9.122 (PD6)
/IMA: J7.2, U6.33 (A5/GTS0), U11.1, U11.2
/LED_GREEN: D2.1 (K), U9.92 (PG7)
/LED_RED: D4.1 (K), U9.91 (PG6)
/LED_YELLOW: D3.1 (K), U9.93 (PG8)
/NAS: U6.13 (B14), U10.4 (A2)
/NBAS: J1.C25 (25C), J2.3, RN6.4 (R3), RN10.4 (R3), U10.16 (B2)
/NBDTACK: J1.A28 (28A), U11.6
/NBIMA: J1.C28 (28C), U11.3
/NBLD: J1.C26 (26C), J2.4, RN6.5 (R4), RN10.3 (R2), U10.15 (B3)
/NBRESET: J1.C24 (24C), J10.8, RN5.9 (R8), RN9.9 (R8), U1.11 (B7)
/NBUD: J1.A26 (26A), J2.5, RN6.6 (R5), RN10.2 (R1), U10.14 (B4)
/NCERAM: J18.1, U6.39 (B1), U8.26 (CE#), U9.125 (PG10)
/NCEROM: J17.1, U6.20 (A15), U7.26 (CE), U9.127 (PG12)
/NLD: U8.15 (LB#), U9.141 (PE0), U10.5 (A3)
/NOE: J19.1, U6.38 (A1), U7.28 (OE), U8.28 (OE#), U9.118 (PD4)
/NPS: U6.14 (B15), U10.3 (A1)
/NRESET: D1.1 (K), U1.9 (A7), U7.12 (RST)
/NUD: U8.14 (UB#), U9.142 (PE1), U10.6 (A4)
/NWE: J20.1, U6.37 (A2), U7.11 (WE), U8.11 (WE#), U9.119 (PD5)
/OE245: J23.1, U4.19 (nOE), U5.19 (nOE), U6.32 (A6/GTS3)
/RD0: J11.1, RN1.2 (R1.2), RN11.2 (R1), RN13.2 (R1), U4.18 (B0)
/RD1: J11.2, RN2.2 (R1.2), RN11.3 (R2), RN13.3 (R2), U4.17 (B1)
/RD2: J11.3, RN1.4 (R2.2), RN11.4 (R3), RN13.4 (R3), U4.16 (B2)
/RD3: J11.4, RN2.4 (R2.2), RN11.5 (R4), RN13.5 (R4), U4.15 (B3)
/RD4: J11.5, RN1.6 (R3.2), RN11.6 (R5), RN13.6 (R5), U4.14 (B4)
/RD5: J11.6, RN2.6 (R3.2), RN11.7 (R6), RN13.7 (R6), U4.13 (B5)
/RD6: J11.7, RN1.8 (R4.2), RN11.8 (R7), RN13.8 (R7), U4.12 (B6)
/RD7: J11.8, RN2.8 (R4.2), RN11.9 (R8), RN13.9 (R8), U4.11 (B7)
/RD8: J12.1, RN12.2 (R1), RN14.2 (R1), RN15.2 (R1.2), U5.18 (B0)
/RD9: J12.2, RN12.3 (R2), RN14.3 (R2), RN16.2 (R1.2), U5.17 (B1)
/RD10: J12.3, RN12.4 (R3), RN14.4 (R3), RN15.4 (R2.2), U5.16 (B2)
/RD11: J12.4, RN12.5 (R4), RN14.5 (R4), RN16.4 (R2.2), U5.15 (B3)
/RD12: J12.5, RN12.6 (R5), RN14.6 (R5), RN15.6 (R3.2), U5.14 (B4)
/RD13: J12.6, RN12.7 (R6), RN14.7 (R6), RN16.6 (R3.2), U5.13 (B5)
/RD14: J12.7, RN12.8 (R7), RN14.8 (R7), RN15.8 (R4.2), U5.12 (B6)
/RD15: J12.8, RN12.9 (R8), RN14.9 (R8), RN16.8 (R4.2), U5.11 (B7)
/RNW: U4.1 (DIR), U5.1 (DIR), U6.18 (I2), U10.2 (A0)
/ROMADR0: J13.1, U6.21 (A14), U7.16 (A18), U8.16 (A18)
/ROMADR1: J16.1, U6.19 (A16), U7.9 (A19), U8.9 (A19)
/ROMADR2: J15.1, U6.22 (A13), U7.10 (A20), U8.10 (A20)
/ROMADR3: J14.1, U6.23 (A12), U7.13 (A21), U8.13 (A21)
/STM32_BUSEN: J22.1, SW1.9, U1.19 (nOE), U2.19 (nOE), U3.19 (nOE), U6.34 (A4/GTS1), U9.128 (PG13), U10.19 (nOE)
/STM32_RESET: C22.1, D1.2 (A), J5.15, R1.2, SW1.10, U9.25 (NRST)
/STM32_TCK: J5.9, R8.2, U9.109 (PA14)
/STM32_TDI: J5.5, R7.1, U9.110 (PA15)
/STM32_TDO: J5.13, R5.1, U9.133 (PB3)
/STM32_TMS: J5.7, R6.1, U9.105 (PA13)
/STM32_TRST: J5.3, R9.1, U9.134 (PB4)
/TCK: J4.6, U6.11 (TCK)
/TDI: J4.10, U6.9 (TDI)
/TDO: J4.8, U6.24 (TDO)
/TMS: J4.4, U6.10 (TMS)
/USB_N: R13.2, U9.103 (PA11)
/USB_P: R12.1, U9.104 (PA12)
GND: C1.2, C2.2, C3.2, C4.2, C5.2, C6.2, C7.2, C8.2, C9.2, C10.2, C11.2, C12.2, C13.2, C14.2, C15.2, C16.2, C17.2, C18.2, C19.2, C20.2, C21.2, C22.2, C23.2, C24.2, C25.2, C26.2, C27.2, C28.2, C29.2, C30.2, C31.2, C32.2, J1.A1 (1A), J1.A8 (8A), J1.A31 (31A), J1.C14 (14C), J1.C32 (32C), J3.5 (GND), J3.6 (Shield), J4.1, J4.3, J4.5, J4.7, J4.9, J4.11, J4.13, J5.4, J5.6, J5.8, J5.10, J5.12, J5.14, J5.16, J5.18, J5.20, J6.3, J25.1, J26.1, J27.1, J28.1, R8.1, R11.2, R14.2, R15.1, RN7.1 (common), RN8.1 (common), RN9.1 (common), RN10.1 (common), RN13.1 (common), RN14.1 (common), SW1.1, SW1.2, SW1.3, SW1.4, SW1.5, SW1.6, SW1.7, SW1.8, U1.1 (DIR), U1.10 (GND), U2.1 (DIR), U2.10 (GND), U3.1 (DIR), U3.10 (GND), U4.10 (GND), U5.10 (GND), U6.4 (GND), U6.17 (GND), U6.25 (GND), U7.27 (VSS), U7.46 (VSS), U8.27 (VSS), U8.46 (VSS), U9.16 (VSS), U9.31 (VSSA), U9.38 (VSS), U9.51 (VSS), U9.61 (VSS), U9.83 (VSS), U9.94 (VSS), U9.107 (VSS), U9.120 (VSS), U9.130 (VSS), U10.1 (DIR), U10.10 (GND), U11.7 (GND), U13.1 (GND)
unnamed: C23.1, R10.2, U9.23 (PH0), Y1.1
unnamed: C24.1, R10.1, U9.24 (PH1), Y1.2
unnamed: C25.1, U9.71 (VCAP_1)
unnamed: C26.1, U9.106 (VCAP_2)
unnamed: D2.2 (A), R2.2
unnamed: D3.2 (A), R3.2
unnamed: D4.2 (A), R4.2
unnamed: D5.2 (A), J1.C2 (2C), J1.C31 (31C)
unnamed: D6.2 (A), J3.1 (VBUS)
unnamed: J3.2 (D-), R13.1
unnamed: J3.3 (D+), R12.2
unnamed: J6.1, U9.101 (PA9)
unnamed: J6.2, U9.102 (PA10)
unnamed: R11.1, U9.138 (BOOT0)
unnamed: R14.1, U10.11 (B7), U10.12 (B6), U10.13 (B5)
unnamed: R15.2, U9.48 (PB2)

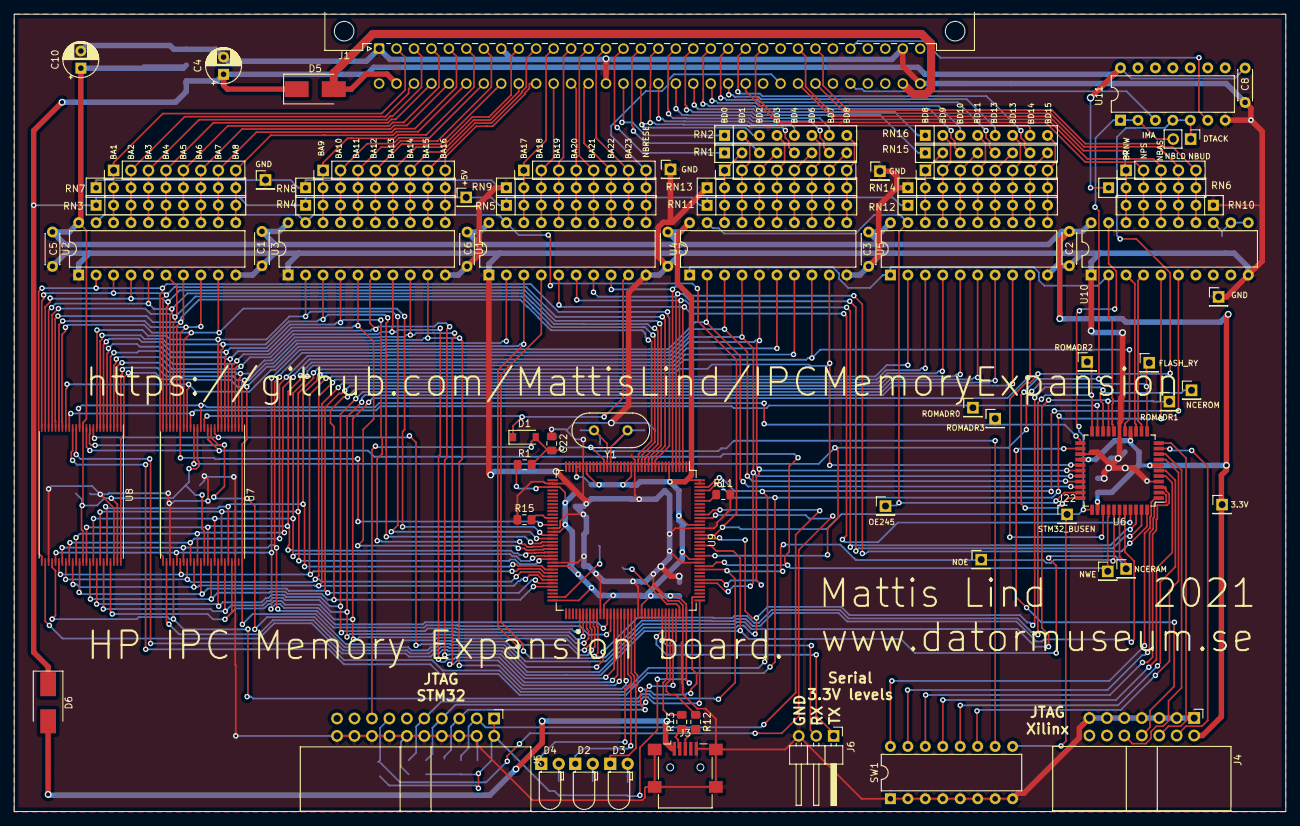
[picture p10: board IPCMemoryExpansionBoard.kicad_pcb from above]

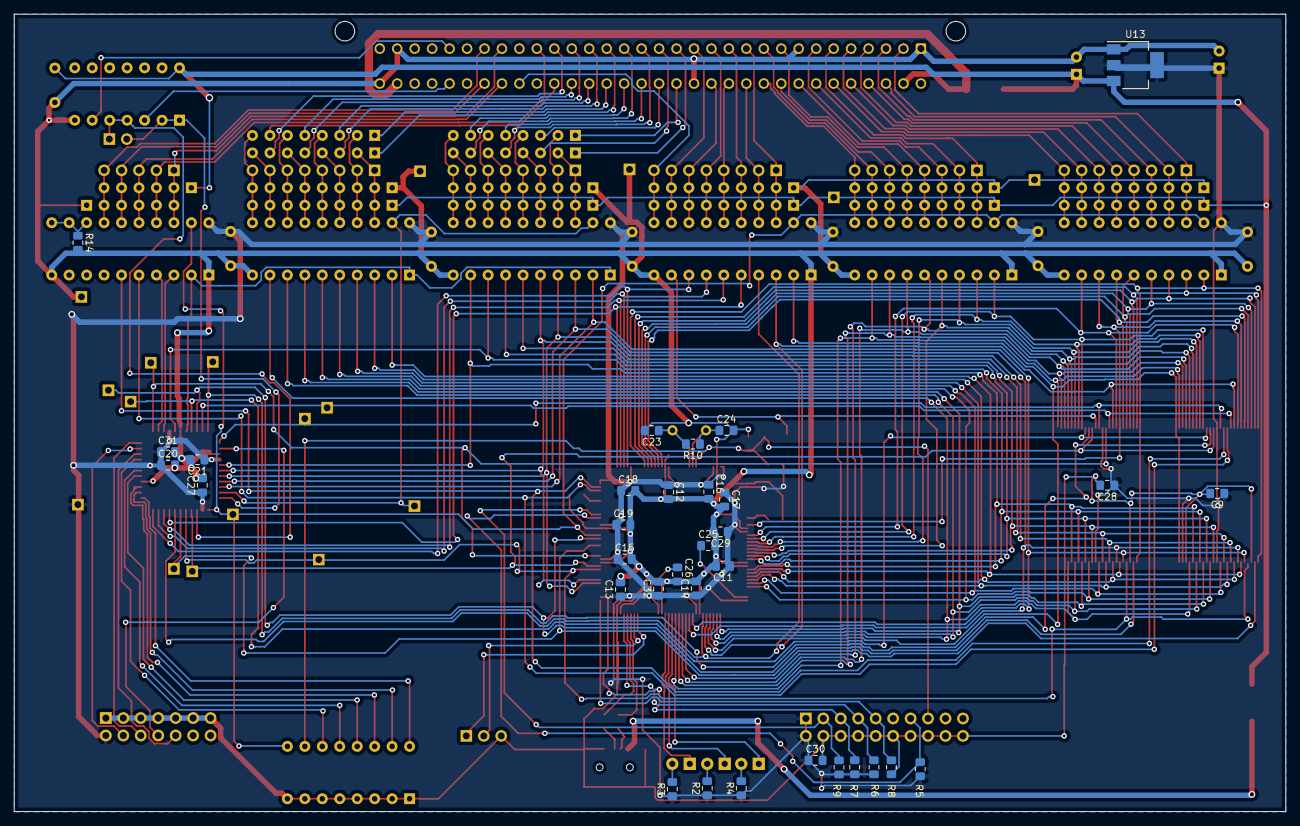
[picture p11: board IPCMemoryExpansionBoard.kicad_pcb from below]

Board: 2 copper layers, 185.0 x 116.0 mm, 112 parts (33 on the bottom side), 161 nets.

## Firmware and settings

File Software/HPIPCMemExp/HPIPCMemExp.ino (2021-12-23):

/*
HP IPC Memory Expansion controller
*/

#include "stm32f4xx.h"


 

//pointer used to write to start address of FSMC
 

volatile uint16_t* sram = (uint16_t*)0x68000000;
volatile uint16_t* flash = (uint16_t*)0x6C000000;

volatile uint16_t dummy;

 

void FSMC_setup(void){
 

    //enable RCC for FSMC and both GPIO ports
 

    RCC->AHB3ENR |= RCC_AHB3ENR_FSMCEN;
    RCC->AHB1ENR |= RCC_AHB1ENR_GPIODEN | RCC_AHB1ENR_GPIOEEN | RCC_AHB1ENR_GPIOFEN | RCC_AHB1ENR_GPIOGEN;

    //setup other pins as AF
 

    GPIOD->MODER |= GPIO_MODER_MODER0_1 | GPIO_MODER_MODER1_1 | GPIO_MODER_MODER4_1 | GPIO_MODER_MODER5_1  | GPIO_MODER_MODER8_1 | GPIO_MODER_MODER9_1 | GPIO_MODER_MODER10_1 | GPIO_MODER_MODER11_1 | GPIO_MODER_MODER12_1 | GPIO_MODER_MODER13_1 | GPIO_MODER_MODER14_1 | GPIO_MODER_MODER15_1;
    GPIOE->MODER |= GPIO_MODER_MODER0_1 | GPIO_MODER_MODER1_1 | GPIO_MODER_MODER3_1 | GPIO_MODER_MODER4_1 | GPIO_MODER_MODER5_1 | GPIO_MODER_MODER6_1 |  GPIO_MODER_MODER7_1  | GPIO_MODER_MODER8_1  | GPIO_MODER_MODER9_1  | GPIO_MODER_MODER10_1  | GPIO_MODER_MODER11_1 | GPIO_MODER_MODER12_1 | GPIO_MODER_MODER13_1 | GPIO_MODER_MODER14_1 |  GPIO_MODER_MODER15_1;    
    GPIOF->MODER |= GPIO_MODER_MODER0_1 | GPIO_MODER_MODER1_1 | GPIO_MODER_MODER2_1 | GPIO_MODER_MODER3_1 | GPIO_MODER_MODER4_1 | GPIO_MODER_MODER5_1 | GPIO_MODER_MODER12_1 |  GPIO_MODER_MODER13_1  | GPIO_MODER_MODER14_1  | GPIO_MODER_MODER15_1;
    GPIOG->MODER |= GPIO_MODER_MODER0_1 | GPIO_MODER_MODER1_1 | GPIO_MODER_MODER2_1 | GPIO_MODER_MODER3_1 | GPIO_MODER_MODER4_1 | GPIO_MODER_MODER5_1 |  GPIO_MODER_MODER10_1 |  GPIO_MODER_MODER12_1;
    //setup pins as PP
 

    GPIOD->OTYPER = 0x00000000;
    GPIOE->OTYPER = 0x00000000;
    GPIOF->OTYPER = 0x00000000;
    GPIOG->OTYPER = 0x00000000;
 

    //set speed to 100MHz
 

    GPIOD->OSPEEDR = 0xFFFFFFFF;
    GPIOE->OSPEEDR = 0xFFFFFFFF;
    GPIOF->OSPEEDR = 0xFFFFFFFF;
    GPIOG->OSPEEDR = 0xFFFFFFFF;
 

    //set NO pull-up or pull-down
 

    GPIOD->PUPDR = 0x00000000;
    GPIOE->PUPDR = 0x00000000;
    GPIOF->PUPDR = 0x00000000;
    GPIOG->PUPDR = 0x00000000;
 

    //set other pins to AF12 i.e as FSMC pins
 

    GPIOD->AFR[0] |= (GPIO_AF12_FSMC << (0 * 4)) | (GPIO_AF12_FSMC << (1 * 4)) | (GPIO_AF12_FSMC << (4 * 4)) | (GPIO_AF12_FSMC << (5 * 4));
    GPIOD->AFR[1] |= (GPIO_AF12_FSMC << ((8 - 8) * 4)) | (GPIO_AF12_FSMC << ((9 - 8) * 4)) | (GPIO_AF12_FSMC << ((10 - 8) * 4)) | (GPIO_AF12_FSMC << ((11 - 8) * 4)) | (GPIO_AF12_FSMC << ((12 - 8) * 4)) | (GPIO_AF12_FSMC << ((13 - 8) * 4)) | (GPIO_AF12_FSMC << ((14 - 8) * 4)) | (GPIO_AF12_FSMC << ((15 - 8) * 4));
    GPIOE->AFR[0] |= (GPIO_AF12_FSMC << (0 * 4)) | (GPIO_AF12_FSMC << (1 * 4))  | (GPIO_AF12_FSMC << (3 * 4)) | (GPIO_AF12_FSMC << (4 * 4)) | (GPIO_AF12_FSMC << (5 * 4)) | (GPIO_AF12_FSMC << (6 * 4)) | (GPIO_AF12_FSMC << (7 * 4));
    GPIOE->AFR[1] |= (GPIO_AF12_FSMC << ((8 - 8) * 4)) | (GPIO_AF12_FSMC << ((9 - 8) * 4)) | (GPIO_AF12_FSMC << ((10 - 8) * 4)) | (GPIO_AF12_FSMC << ((11 - 8) * 4)) | (GPIO_AF12_FSMC << ((12 - 8) * 4)) | (GPIO_AF12_FSMC << ((13 - 8) * 4)) | (GPIO_AF12_FSMC << ((14 - 8) * 4)) | (GPIO_AF12_FSMC << ((15 - 8) * 4));
    GPIOF->AFR[0] |= (GPIO_AF12_FSMC << (0 * 4)) | (GPIO_AF12_FSMC << (1 * 4)) | (GPIO_AF12_FSMC << (2 * 4)) | (GPIO_AF12_FSMC << (3 * 4)) | (GPIO_AF12_FSMC << (4 * 4)) | (GPIO_AF12_FSMC << (5 * 4));
    GPIOF->AFR[1] |= (GPIO_AF12_FSMC << ((12 - 8) * 4)) | (GPIO_AF12_FSMC << ((13 - 8) * 4)) | (GPIO_AF12_FSMC << ((14 - 8) * 4)) | (GPIO_AF12_FSMC << ((15 - 8) * 4));
    GPIOG->AFR[0] |= (GPIO_AF12_FSMC << (0 * 4)) | (GPIO_AF12_FSMC << (1 * 4)) | (GPIO_AF12_FSMC << (2 * 4)) | (GPIO_AF12_FSMC << (3 * 4)) | (GPIO_AF12_FSMC << (4 * 4)) | (GPIO_AF12_FSMC << (5 * 4));
    GPIOG->AFR[1] |= (GPIO_AF12_FSMC << ((10 - 8) * 4)) | (GPIO_AF12_FSMC << ((12 - 8) * 4)) ;

 

    //setup FSMC on Bank1 NORSRAM1


    //disable ASYNCWAIT:
    FSMC_Bank1->BTCR[4] &= ~FSMC_BCR1_ASYNCWAIT;
    //disable Extended mode
    FSMC_Bank1->BTCR[4] &= ~FSMC_BCR1_EXTMOD;
    //disable the wait for NWAIT signal
    FSMC_Bank1->BTCR[4] &= ~FSMC_BCR1_WAITEN;
    //write enable
    FSMC_Bank1->BTCR[4] |= FSMC_BCR1_WREN;
    //disable wrap mode
    FSMC_Bank1->BTCR[4] &= ~FSMC_BCR1_WRAPMOD;
    //disable Burst mode
    FSMC_Bank1->BTCR[4] &= ~FSMC_BCR1_BURSTEN;
    //enable Flash access
    FSMC_Bank1->BTCR[4] |= FSMC_BCR1_FACCEN;
    //set data bus width to 16 bit
    FSMC_Bank1->BTCR[4] |= FSMC_BCR1_MWID_0;
    //set to SRAM type
    FSMC_Bank1->BTCR[4] &= ~(FSMC_BCR1_MTYP_0 | FSMC_BCR1_MTYP_1);
    //disable Address/data multiplexing
    FSMC_Bank1->BTCR[4] &= ~FSMC_BCR1_MUXEN;
    //enable Memory bank
    FSMC_Bank1->BTCR[4] |= FSMC_BCR1_MBKEN;
    //setup timings of FSCM
    //FSMC_Bank1->BTCR[5] |= FSMC_BTR1_ADDSET_1 | FSMC_BTR1_DATAST_1;
    // Bank1 NOR/SRAM control register configuration
    //set access mode A
    //FSMC_Bank1->BTCR[5] &= ~FSMC_BTR1_ACCMOD;
    // Access mode 0 , 55 ns
    FSMC_Bank1->BTCR[5]  = 1 << 16 | 9 << 8 | 1;
    //set short bus turn around
    //FSMC_Bank1->BTCR[5] &= ~(FSMC_BTR1_BUSTURN_0 | FSMC_BTR1_BUSTURN_1 | FSMC_BTR1_BUSTURN_2 |FSMC_BTR1_BUSTURN_3);



    //setup FSMC on Bank1 NORSRAM1


    //disable ASYNCWAIT:
    FSMC_Bank1->BTCR[6] &= ~FSMC_BCR1_ASYNCWAIT;
    //disable Extended mode
    FSMC_Bank1->BTCR[6] &= ~FSMC_BCR1_EXTMOD;
    //disable the wait for NWAIT signal
    FSMC_Bank1->BTCR[6] &= ~FSMC_BCR1_WAITEN;
    //write enable
    FSMC_Bank1->BTCR[6] |= FSMC_BCR1_WREN;
    //disable wrap mode
    FSMC_Bank1->BTCR[6] &= ~FSMC_BCR1_WRAPMOD;
    //disable Burst mode
    FSMC_Bank1->BTCR[6] &= ~FSMC_BCR1_BURSTEN;
    //enable Flash access
    FSMC_Bank1->BTCR[6] |= FSMC_BCR1_FACCEN;
    //set data bus width to 16 bit
    FSMC_Bank1->BTCR[6] |= FSMC_BCR1_MWID_0;
    //set to NOR FLASH type
    FSMC_Bank1->BTCR[6] &= ~FSMC_BCR1_MTYP_0;
    FSMC_Bank1->BTCR[6] |= FSMC_BCR1_MTYP_1;
    //disable Address/data multiplexing
    FSMC_Bank1->BTCR[6] &= ~FSMC_BCR1_MUXEN;
    //enable Memory bank
    FSMC_Bank1->BTCR[6] |= FSMC_BCR1_MBKEN;
    //setup timings of FSCM
    //FSMC_Bank1->BTCR[7] |= FSMC_BTR1_ADDSET_1 | FSMC_BTR1_DATAST_0 ;
    // Access mode 0 , 90 ns
    FSMC_Bank1->BTCR[7]  = 1 << 16 | 24 << 8 | 1;
    // Bank1 NOR/SRAM control register configuration
    //set access mode A
    //FSMC_Bank1->BTCR[7] &= ~FSMC_BTR1_ACCMOD;
    //set short bus turn around
    //FSMC_Bank1->BTCR[7] &= ~(FSMC_BTR1_BUSTURN_0 | FSMC_BTR1_BUSTURN_1 | FSMC_BTR1_BUSTURN_2 |FSMC_BTR1_BUSTURN_3);
}

int toggle = 1;

// the setup function runs once when you press reset or power the board
void setup() {
  // initialize digital pin LED_BUILTIN as an output.
  pinMode(PG6, OUTPUT);
  pinMode(PG7, OUTPUT);
  pinMode(PG8, OUTPUT);
  pinMode(PG13, OUTPUT);
  pinMode(PD6, INPUT);
  pinMode(PG10, INPUT);
  pinMode(PG12, INPUT);
  pinMode(PD4, INPUT);
  pinMode(PD5, INPUT);
  pinMode(PE0, INPUT);
  pinMode(PE1, INPUT);
  //pinMode(PD8, INPUT_PULLDOWN);
  //digitalWrite(PD8,LOW);
  Serial.begin(9600);
  digitalWrite(PG13, toggle);  // Enable the STM32 on the bus. Disable LVC245 drivers.
  //FSMC_setup();
  Serial.write("IPCMEMTESTER> ");
}

void flashSectorErase (uint16_t sector) {
  flash[0x555] = 0xAA;
  flash[0x2AA] = 0x55;
  flash[0x555] = 0x80;
  flash[0x555] = 0xAA;
  flash[0x2AA] = 0x55;
  flash[sector] = 0x50; 
  dummy++;
  dummy++;
  dummy++;
    while (digitalRead(PD6)==0) {
    dummy = 1;
  } 
}

void flashBlockErase (uint16_t block) {
  flash[0x555] = 0xAA;
  flash[0x2AA] = 0x55;
  flash[0x555] = 0x80;
  flash[0x555] = 0xAA;
  flash[0x2AA] = 0x55;
  flash[block] = 0x30; 
  dummy++;
  dummy++;
  dummy++;
    while (digitalRead(PD6)==0) {
    dummy = 1;
  } 
}

void flashChipErase () {
  //
  flash[0x555] = 0xAA;
  flash[0x2AA] = 0x55;
  flash[0x555] = 0x80;
  flash[0x555] = 0xAA;
  flash[0x2AA] = 0x55;
  flash[0x555] = 0x10;
  dummy++;
  dummy++;
  dummy++;
  while (digitalRead(PD6)==0) {
    dummy++;
    dummy++;
    dummy++;
  }
}

uint16_t flashReadManufacturerID () {
  uint16_t tmp;
  flash[0x555] = 0xAA;
  flash[0x2AA] = 0x55;
  flash[0x555] = 0x90;
  tmp = flash[0];
  flash[0x555] = 0xAA;
  flash[0x2AA] = 0x55;
  flash[0x555] = 0xF0;
  return tmp;    
}

uint16_t flashReadDeviceID () {
  uint16_t tmp;
  flash[0x555] = 0xAA;
  flash[0x2AA] = 0x55;
  flash[0x555] = 0x90;
  tmp = flash[1];
  flash[0x555] = 0xAA;
  flash[0x2AA] = 0x55;
  flash[0x555] = 0xF0;
  return tmp;    
}

void flashWordProgram ( uint32_t address, uint16_t data ) {
  
  //Serial.print("FLASH WORD PROGRAM");
  //Serial.print(address, HEX);
  //Serial.print(" ");
  //Serial.print(data, HEX);
  //Serial.println();
  flash[0x555] = 0xAA;
  flash[0x2AA] = 0x55;
  flash[0x555] = 0xA0;  
  flash[address] = data;
  dummy++;
  dummy++;
  dummy++;
  while (digitalRead(PD6)==0) {
    dummy++;
    dummy++;
  }
}

void sramTest () {
  int i; 
  for (i=0; i<4194304; i++) {
    sram[i] = (i>>16) ^ (i & 0xffff) ;
  }
  for (i=0; i<4194304; i++) {
    if (((i>>16) ^ (i & 0xffff)) != sram[i]) {
      Serial.print("SRAM ERROR: ");
      Serial.print(i,HEX);
      Serial.print(" ");
      Serial.println(sram[i],HEX);
      delay(1);
    }
    if ((i % 65536) == 0) {
      Serial.print(".");
    }
  } 
  Serial.println("OK"); 
}

void flashTest () {
  int i; 
  Serial.println("FLASH PROGRAMMING");
  for (i=0; i<4194304; i++) {
  //for (i=0; i<65536; i++) {
    flashWordProgram(i, (i>>16) ^ (i & 0xffff));
    if ((i % 65536) == 0) {
      Serial.print(".");
    }
  }
  Serial.println("OK");
  Serial.println("CHECKING");
  for (i=0; i<4194304; i++) {
  //for (i=0; i<65536; i++) {
    if (((i>>16) ^ (i & 0xffff)) != flash[i]) {
      Serial.print("FLASH ERROR: ");
      Serial.print(i,HEX);
      Serial.print(" ");
      Serial.println(flash[i],HEX);
      delay(1);
    }
    if ((i % 65536) == 0) {
      Serial.print(".");
    }
  } 
  Serial.println("OK");   
}

void flashEmptyCheck () {
  int i; 
  for (i=0; i<4194304; i++) {
    if (0xffff != flash[i]) {
      Serial.print("FLASH NOT EMPTY: ");
      Serial.print(i,HEX);
      Serial.print(" ");
      Serial.println(flash[i],HEX);
      delay(1);
    }
    if ((i % 65536) == 0) {
      Serial.print(".");
    }
  } 
  Serial.println("OK"); 
}

int state = 0;
int address;
int numHexChars = 0;
int hexValue;
int sramEnabled=1;
uint16_t data=0, readin;
uint16_t flashdata=0;
char command;
// the loop function runs over and over again forever
void loop() {  
  char ch;
  if (Serial.available()) {
    ch = Serial.read();
    if (ch > 0x60) ch -= 0x20;
    if (state == 0) {
      switch (ch) {
        case 'L':
          Serial.write('L');
          Serial.write(' ');
          state = 1;
          hexValue = 0;
          numHexChars = 0;
          command = ch;
        break;
        case 'S':
          Serial.println("SRAM SELECTED");
          Serial.write("IPCMEMTESTER> ");
          sramEnabled = 1;
          break;
        case 'C':
          flashChipErase();
          Serial.println("FLASH CLEARED");
          Serial.write("IPCMEMTESTER> ");
        break;
        case 'H':
          Serial.println();
          Serial.println("H - Help");
          Serial.println("C - Clear flash");
          Serial.println("E - Examine memory");
          Serial.println("D - Deposit into memory");
          Serial.println("S - Select SRAM");
          Serial.println("F - Select Flash");
          Serial.println("L - Load address");
          Serial.println("T - Sector Erase");
          Serial.println("A - Flash test");
          Serial.println("B - SRAM test");
          Serial.println("G - Flash blank check");
          Serial.println("R - Read pins");
          Serial.println("U - Toggle STM32_BUSEN");
          Serial.println();
          Serial.write("IPCMEMTESTER> ");
          break;
        case 'R':
          Serial.println();
          Serial.print("NCEROM: ");
          Serial.println(digitalRead(PG12), DEC); 
          Serial.print("NCERAM: ");
          Serial.println(digitalRead(PG10), DEC);
          Serial.print("NWE: ");
          Serial.println(digitalRead(PD5), DEC);
          Serial.print("NOE: ");
          Serial.println(digitalRead(PD4), DEC);                              
          Serial.print("NLD: ");
          Serial.println(digitalRead(PE0), DEC);                              
          Serial.print("NUD: ");
          Serial.println(digitalRead(PE1), DEC); 
          Serial.println();
          Serial.write("IPCMEMTESTER> ");
          break;  
        case 'U':
           digitalWrite(PG13, toggle ^= 1);   
           Serial.println(); 
           Serial.write("IPCMEMTESTER> ");
           break;                       
        case 'A':
          Serial.println();
          flashTest();
          Serial.println();
          Serial.write("IPCMEMTESTER> ");
          break;
        case 'B':
          Serial.println();
          sramTest();
          Serial.println();
          Serial.write("IPCMEMTESTER> ");
          break;
        case 'G':
          Serial.println();
          flashEmptyCheck();
          Serial.println();
          Serial.write("IPCMEMTESTER> ");
          break;
        case 'T':
          Serial.write('T');
          Serial.write(' ');
          state = 1;
          hexValue = 0;
          numHexChars = 0;
          command = ch;          
          break;
        case 'F':
          Serial.println("FLASH SELECTED");
          Serial.write("IPCMEMTESTER> ");
          sramEnabled = 0;
          break;  
        case 'E':
          Serial.write('E');
          Serial.write(' ');
          Serial.print(address, HEX);
          Serial.write(' ');
          if (sramEnabled) {
            Serial.print(sram[address], HEX );
          } else {
            Serial.print(flash[address], HEX );         
          }
          address++;
          Serial.println();
          Serial.write("IPCMEMTESTER> ");
        break;
        case 'D':
          Serial.write('D');
          Serial.write(' ');
          Serial.print(address, HEX);
          Serial.write(' ');
          if (sramEnabled) {
            Serial.print(sram[address], HEX );
          } else {
            Serial.print(flash[address], HEX );         
          }
          Serial.write(' ');
          hexValue = 0;
          numHexChars = 0;
          command = ch;
          state = 1;
          
        break;
        case '\r':
        case '\n':
          Serial.println();
          Serial.write("IPCMEMTESTER> ");
        break;
      }
    } else if (state == 1) {
        // collect hex digits
        if (ch >= 'A' && ch <= 'F' && numHexChars < 8) {
          Serial.write(ch);
          hexValue = (hexValue << 4) | (0x0f & (ch -'A' + 10)); 
          numHexChars++;  
        } else if (ch >= '0' && ch <= '9' && numHexChars < 8) {
          Serial.write(ch);
          hexValue = (hexValue << 4) | (0x0f & (ch -'0'));
          numHexChars++;
        } else if ((ch == '\r') || (numHexChars >= 8)) {
          switch (command) {
            case 'L':
              address = hexValue;
              break;
            case 'D':
              if (sramEnabled) {
                sram[address] = hexValue;
              } else {
                flashWordProgram(address, hexValue);
              }
              address++;
              break;
            case 'T':
             flashSectorErase(hexValue);
             break; 
          }
          //Serial.println();
          //Serial.print(hexValue, HEX);
          Serial.println();
          Serial.write("IPCMEMTESTER> ");
          state = 0;
        } else {
          Serial.write("?\n\r");
          Serial.write("IPCMEMTESTER> ");
          state = 0;
        }
    }
  }
  /*Serial.println("FLASH ERASE");
  digitalWrite(PG8, HIGH);
  digitalWrite(PG7, HIGH);  
  digitalWrite(PG6, LOW);   
  flashChipErase();
  Serial.print("Manufacturer ID:");
  Serial.print(flashReadManufacturerID(), HEX);
  Serial.println();
  Serial.println("FLASH EMPTY CHECK");
  flashEmptyCheck ();
  digitalWrite(PG8, HIGH);
  digitalWrite(PG7, LOW);   
  digitalWrite(PG6, HIGH);   
  Serial.print("Device ID:");
  Serial.print(flashReadDeviceID(), HEX);
  Serial.println();
  delay(200);
  Serial.println("SRAMTEST");
  sramTest  ();
  digitalWrite(PG8, LOW);
  digitalWrite(PG7, HIGH);  
  digitalWrite(PG6, HIGH);  
  Serial.println("FLASHTEST");
  flashTest(); */
}

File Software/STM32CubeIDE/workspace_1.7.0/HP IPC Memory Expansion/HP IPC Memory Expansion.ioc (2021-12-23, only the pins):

Mcu.UserName=STM32F407ZETx
PA10.Signal=USART1_RX
PA11.Signal=USB_OTG_FS_DM
PA12.Signal=USB_OTG_FS_DP
PA13.Signal=SYS_JTMS-SWDIO
PA14.Signal=SYS_JTCK-SWCLK
PA9.Signal=USART1_TX
PD0.Signal=FSMC_D2_DA2
PD1.Signal=FSMC_D3_DA3
PD10.Signal=FSMC_D15_DA15
PD11.Signal=FSMC_A16_CLE
PD12.Signal=FSMC_A17_ALE
PD13.Signal=FSMC_A18
PD14.Signal=FSMC_D0_DA0
PD15.Signal=FSMC_D1_DA1
PD4.Signal=FSMC_NOE
PD5.Signal=FSMC_NWE
PD6.GPIO_Label=RY_WAIT
PD6.Signal=GPIO_Input
PD8.Signal=FSMC_D13_DA13
PD9.Signal=FSMC_D14_DA14
PE0.Signal=FSMC_NBL0
PE1.Signal=FSMC_NBL1
PE10.Signal=FSMC_D7_DA7
PE11.Signal=FSMC_D8_DA8
PE12.Signal=FSMC_D9_DA9
PE13.Signal=FSMC_D10_DA10
PE14.Signal=FSMC_D11_DA11
PE15.Signal=FSMC_D12_DA12
PE3.Signal=FSMC_A19
PE4.Signal=FSMC_A20
PE5.Signal=FSMC_A21
PE6.Signal=FSMC_A22
PE7.Signal=FSMC_D4_DA4
PE8.Signal=FSMC_D5_DA5
PE9.Signal=FSMC_D6_DA6
PF0.Signal=FSMC_A0
PF1.Signal=FSMC_A1
PF12.Signal=FSMC_A6
PF13.Signal=FSMC_A7
PF14.Signal=FSMC_A8
PF15.Signal=FSMC_A9
PF2.Signal=FSMC_A2
PF3.Signal=FSMC_A3
PF4.Signal=FSMC_A4
PF5.Signal=FSMC_A5
PG0.Signal=FSMC_A10
PG1.Signal=FSMC_A11
PG10.Signal=FSMC_NE3
PG12.Signal=FSMC_NE4
PG13.GPIO_Label=STM32_ENABLE
PG13.Signal=GPIO_Output
PG2.Signal=FSMC_A12
PG3.Signal=FSMC_A13
PG4.Signal=FSMC_A14
PG5.Signal=FSMC_A15
PG6.GPIO_Label=LED_RED
PG6.Signal=GPIO_Output
PG7.GPIO_Label=LED_YELLOW
PG7.Signal=GPIO_Output
PG8.GPIO_Label=LED_GREEN
PG8.Signal=GPIO_Output
PH0-OSC_IN.Signal=RCC_OSC_IN
PH1-OSC_OUT.Signal=RCC_OSC_OUT

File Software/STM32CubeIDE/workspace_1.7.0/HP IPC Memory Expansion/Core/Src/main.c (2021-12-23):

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
/* Includes ------------------------------------------------------------------*/
#include "main.h"
#include "usart.h"
#include "usb_device.h"
#include "gpio.h"
#include "fsmc.h"


/* USER CODE BEGIN PV */

extern UART_HandleTypeDef huart1;

int count=0;

/* USER CODE END PV */

void SystemClock_Config(void);
/* USER CODE BEGIN PFP */

void setYellow(void);

void clearYellow(void);

void setRed(void);

void clearRed(void);

/* USER CODE END PFP */

/* USER CODE BEGIN 0 */



void blinkGreenTwice() {
	HAL_GPIO_WritePin (LED_GREEN_GPIO_Port, LED_GREEN_Pin, 0);
	HAL_Delay(500);
	HAL_GPIO_WritePin (LED_GREEN_GPIO_Port, LED_GREEN_Pin, 1);
	HAL_Delay(200);
	HAL_GPIO_WritePin (LED_GREEN_GPIO_Port, LED_GREEN_Pin, 0);
	HAL_Delay(500);
	HAL_GPIO_WritePin (LED_GREEN_GPIO_Port, LED_GREEN_Pin, 1);
	HAL_Delay(200);
}

void blinkRedOnce() {
	HAL_GPIO_WritePin (LED_RED_GPIO_Port, LED_RED_Pin, 0);
	HAL_Delay(250);
	HAL_GPIO_WritePin (LED_RED_GPIO_Port, LED_RED_Pin, 1);
	HAL_Delay(200);
}

void blinkYellowOnce() {
	HAL_GPIO_WritePin (LED_YELLOW_GPIO_Port, LED_YELLOW_Pin, 0);
	HAL_Delay(250);
	HAL_GPIO_WritePin (LED_YELLOW_GPIO_Port, LED_YELLOW_Pin, 1);
	HAL_Delay(200);
}



void putStr (char * str) {
	HAL_UART_Transmit(&huart1, (uint8_t *) str, strlen(str), HAL_MAX_DELAY);
}

/* USER CODE END 0 */

/**
  * @brief  The application entry point.
  * @retval int
  */
int main(void)
{
  /* USER CODE BEGIN 1 */

  //char buf [256];

  /* USER CODE END 1 */

  /* MCU Configuration--------------------------------------------------------*/

  /* Reset of all peripherals, Initializes the Flash interface and the Systick. */
  HAL_Init();

  /* Configure the system clock */
  SystemClock_Config();

  /* Initialize all configured peripherals */
  MX_GPIO_Init();
  MX_FSMC_Init();
  MX_USB_DEVICE_Init();
  MX_USART1_UART_Init();

  //HAL_GPIO_WritePin (STM32_ENABLE_GPIO_Port, STM32_ENABLE_Pin, 1);
  /* USER CODE BEGIN 2 */
  clearRed();
  clearYellow();

  /* USER CODE END 2 */

  /* Infinite loop */
  /* USER CODE BEGIN WHILE */
  while (1)
  {
    /* USER CODE END WHILE */

    /* USER CODE BEGIN 3 */
	  //snprintf(buf, 256, "HP IPC MEM EXPANSION TEST %d\n\r", count++);
	  //putStr(buf);
	  blinkGreenTwice();
  }
  /* USER CODE END 3 */
}

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
/**
  * @brief  Period elapsed callback in non blocking mode
  * @note   This function is called  when TIM1 interrupt took place, inside
  * HAL_TIM_IRQHandler(). It makes a direct call to HAL_IncTick() to increment
  * a global variable "uwTick" used as application time base.
  * @param  htim : TIM handle
  * @retval None
  */
void HAL_TIM_PeriodElapsedCallback(TIM_HandleTypeDef *htim)
{
  if (htim->Instance == TIM1) {
    HAL_IncTick();
  }
}

/**
  * @brief  This function is executed in case of error occurrence.
  * @retval None
  */
void Error_Handler(void)
{
  /* USER CODE BEGIN Error_Handler_Debug */
  /* User can add his own implementation to report the HAL error return state */
  __disable_irq();
  while (1)
  {
  }
  /* USER CODE END Error_Handler_Debug */
}

#ifdef  USE_FULL_ASSERT
/**
  * @brief  Reports the name of the source file and the source line number
  *         where the assert_param error has occurred.
  * @param  file: pointer to the source file name
  * @param  line: assert_param error line source number
  * @retval None
  */
void assert_failed(uint8_t *file, uint32_t line)
{
  /* USER CODE BEGIN 6 */
  /* User can add his own implementation to report the file name and line number,
     ex: printf("Wrong parameters value: file %s on line %d\r\n", file, line) */
  /* USER CODE END 6 */
}
#endif /* USE_FULL_ASSERT */

/************************ (C) COPYRIGHT STMicroelectronics *****END OF FILE****/

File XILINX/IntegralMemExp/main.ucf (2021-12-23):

#PACE: Start of Constraints generated by PACE

#PACE: Start of PACE I/O Pin Assignments
NET "ADRIN<0>" LOC = P40 | IOSTANDARD = LVTTL | PULLUP;
NET "ADRIN<1>" LOC = P41 | IOSTANDARD = LVTTL | PULLUP;
NET "ADRIN<2>" LOC = P42 | IOSTANDARD = LVTTL | PULLUP;
NET "ADRIN<3>" LOC = P43 | IOSTANDARD = LVTTL | PULLUP;
NET "ADRIN<4>" LOC = P44 | IOSTANDARD = LVTTL | PULLUP;
NET "D0" LOC = P31 | IOSTANDARD = LVTTL ;
NET "D1" LOC = P30 | IOSTANDARD = LVTTL ;
NET "D2" LOC = P29 | IOSTANDARD = LVTTL ;
NET "D3" LOC = P28 | IOSTANDARD = LVTTL ;
NET "D7" LOC = P27 | IOSTANDARD = LVTTL ;
NET "DIPSW0" LOC = P1 | IOSTANDARD = LVTTL  | PULLUP ;
NET "DIPSW1" LOC = P2 | IOSTANDARD = LVTTL  | PULLUP ;
NET "DIPSW2" LOC = P3 | IOSTANDARD = LVTTL  | PULLUP ;
NET "DIPSW3" LOC = P5 | IOSTANDARD = LVTTL  | PULLUP ;
NET "DIPSW4" LOC = P6 | IOSTANDARD = LVTTL  | PULLUP ;
NET "DIPSW5" LOC = P8 | IOSTANDARD = LVTTL  | PULLUP ;
NET "DTACK" LOC = P36 | IOSTANDARD = LVTTL ;
NET "IMA" LOC = P33 | IOSTANDARD = LVTTL;
NET "NCERAM" LOC = P39 | IOSTANDARD = LVTTL  | PULLUP ;
NET "NCEROM" LOC = P20 | IOSTANDARD = LVTTL  | PULLUP ;
NET "FLASH_RY" LOC = P12 | IOSTANDARD = LVTTL | PULLUP;
NET "NAS" LOC = P13 | IOSTANDARD = LVTTL | PULLUP;
NET "NOE" LOC = P38 | IOSTANDARD = LVTTL  | PULLUP ;
NET "NPS" LOC = P14 | IOSTANDARD = LVTTL | PULLUP;
NET "D6" LOC = P16 | IOSTANDARD = LVTTL;
NET "NWE" LOC = P37 | IOSTANDARD = LVTTL  | PULLUP ;
NET "OE245" LOC = P32 | IOSTANDARD = LVTTL;
NET "RNW" LOC = P18 | IOSTANDARD = LVTTL | PULLUP ;
NET "ROMADR<0>" LOC = P21 | IOSTANDARD = LVTTL;
NET "ROMADR<1>" LOC = P19 | IOSTANDARD = LVTTL;
NET "ROMADR<2>" LOC = P22 | IOSTANDARD = LVTTL;
NET "ROMADR<3>" LOC = P23 | IOSTANDARD = LVTTL;
NET "STM32_BUSEN" LOC = P34 | IOSTANDARD = LVTTL  | PULLUP ;

#PACE: Start of PACE Area Constraints

#PACE: Start of PACE Prohibit Constraints

#PACE: End of Constraints generated by PACE

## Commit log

2021-04-01 Added kicad schematic.
    [IPCMemoryExpansionBoard.kicad_pcb, IPCMemoryExpansionBoard.sch]
2021-04-03 Adding png of the schematic
2021-04-03 Added schematic.
2021-04-25 Updates and fixes.
    [IPCMemoryExpansionBoard.kicad_pcb, IPCMemoryExpansionBoard.sch]
2021-08-23 Update schematic. Fixed PCB. Added zip for gerbers.
    [IPCMemoryExpansionBoard.kicad_pcb, IPCMemoryExpansionBoard.sch]
2021-09-14 Added testbench and fixed a few small issues in the VHDL code.
    [main.ucf]
2021-09-14 Small fixes to the PCB. RESET was short circuit to GND
    [IPCMemoryExpansionBoard-B.Cu.gbr, IPCMemoryExpansionBoard-B.Mask.gbr, IPCMemoryExpansionBoard-B.Paste.gbr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]
2021-12-12 Started work on spin 2.
    [IPCMemoryExpansionBoard.kicad_pcb, IPCMemoryExpansionBoard.sch]
2021-12-22 Made spin 2 of the board
    [IPCMemoryExpansionBoard-B.Cu.gbr, IPCMemoryExpansionBoard-B.Mask.gbr, IPCMemoryExpansionBoard-B.Paste.gbr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]
2021-12-23 Added all the stm32cube files.
2022-01-03 Layout ready.
    [IPCMemoryExpansionBoard-B.Cu.gbr, IPCMemoryExpansionBoard-B.Mask.gbr, IPCMemoryExpansionBoard-B.Paste.gbr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]
2023-09-13 Update README.md
    Add BOM

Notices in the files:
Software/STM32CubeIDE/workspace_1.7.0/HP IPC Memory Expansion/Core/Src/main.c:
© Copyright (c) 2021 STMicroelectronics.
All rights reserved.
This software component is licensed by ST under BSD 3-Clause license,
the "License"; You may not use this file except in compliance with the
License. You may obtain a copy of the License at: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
